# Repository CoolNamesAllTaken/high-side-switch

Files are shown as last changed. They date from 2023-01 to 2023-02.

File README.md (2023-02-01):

# high-side-switch
High side load switch for automotive and aerospace applications.

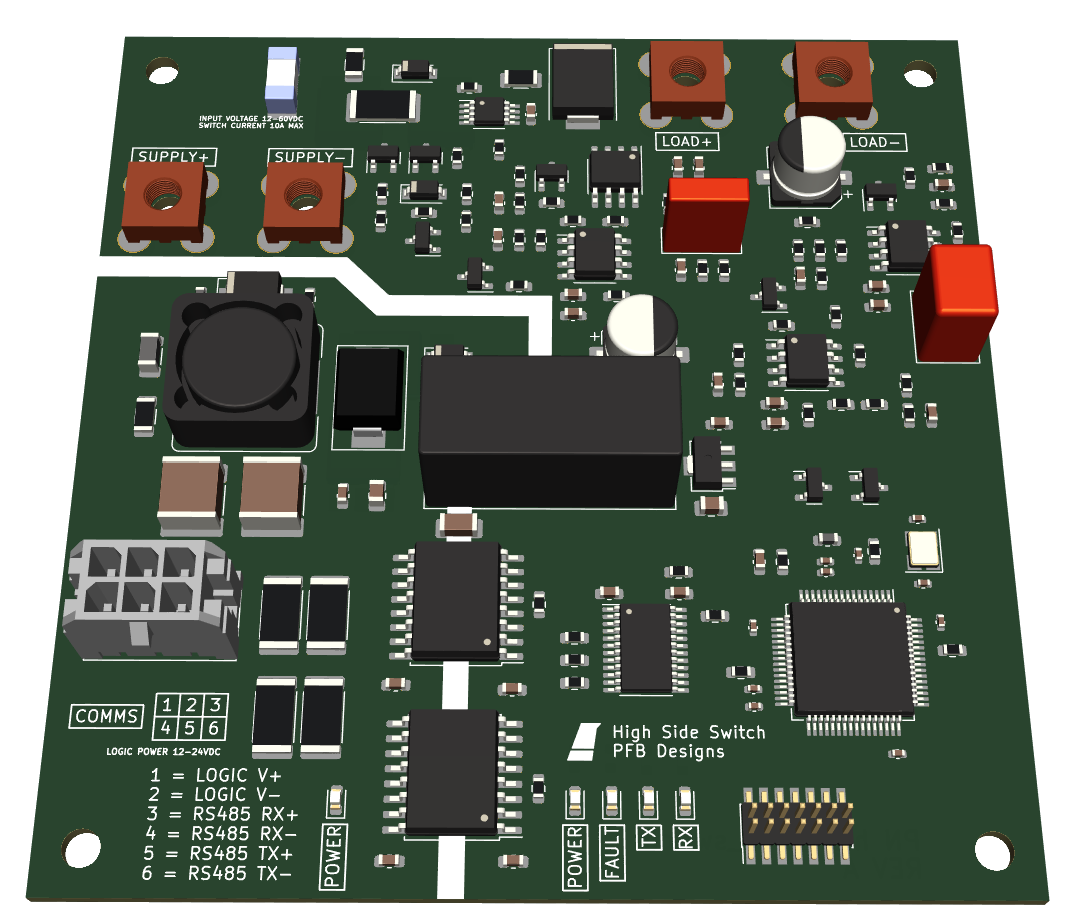
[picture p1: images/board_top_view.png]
Board top view.

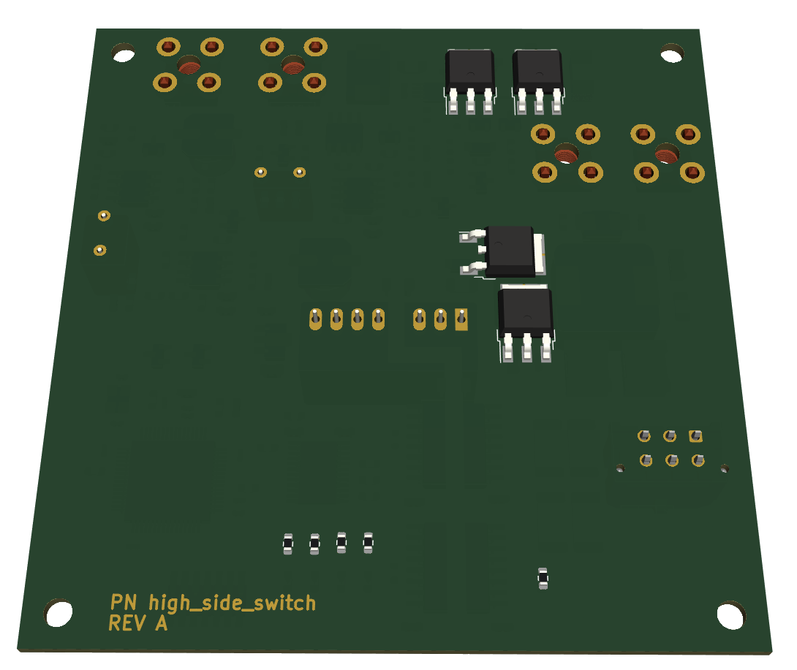
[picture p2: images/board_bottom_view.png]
Board bottom view.

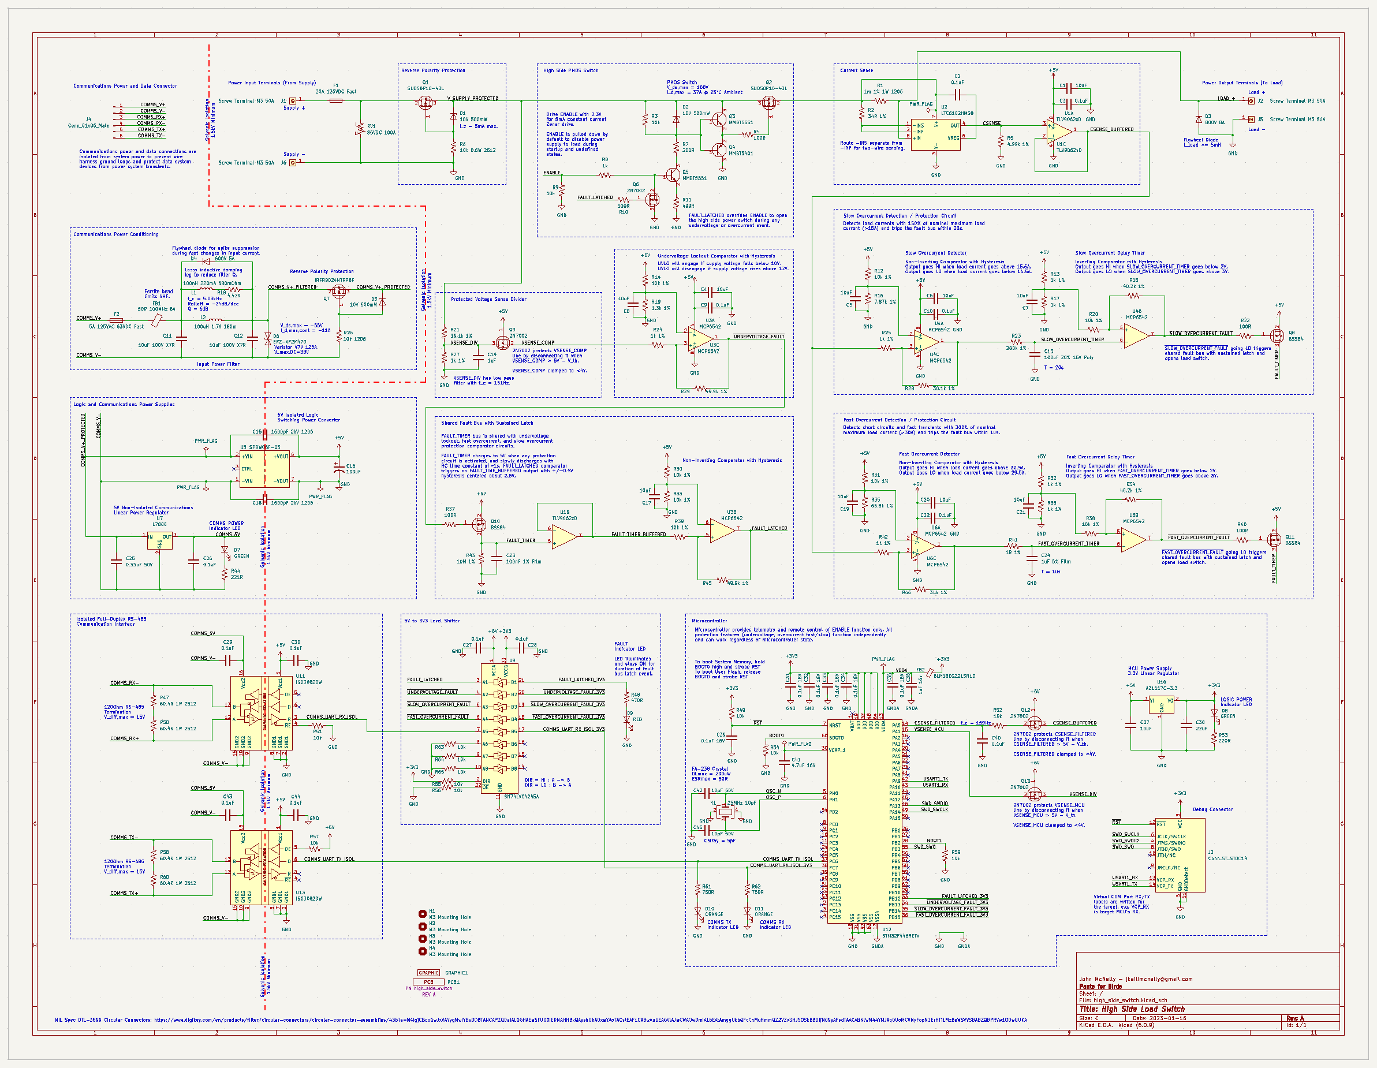
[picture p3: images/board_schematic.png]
Board schematic.


[Design Notes](word/design_notes_high_side_switch.pdf)

[Design Presentation](affinity/Onsite_Presentation_Reliable_Robotics.pdf)

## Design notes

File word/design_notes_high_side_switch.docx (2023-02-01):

# Remote Load Switch

Design Notes

John McNelly

jkailimcnelly@gmail.com

# Design Requirements

This design is required to switch 12-60VDC power into a resistive and inductive load ( L_(load) ≤5mH ). Control signals must be received from, and load measurements with a resolution of 10mA must be reported to, a remote control computer up to 100ft away. The switch must be capable of operating continuously and may be cycled on and off at a frequency lower than 1Hz. The overall design should be tolerant of temperatures between -40°C to +70°C, standard atmospheric pressure, some conducted and radiated EMI, and moderate mechanical shock and vibration.

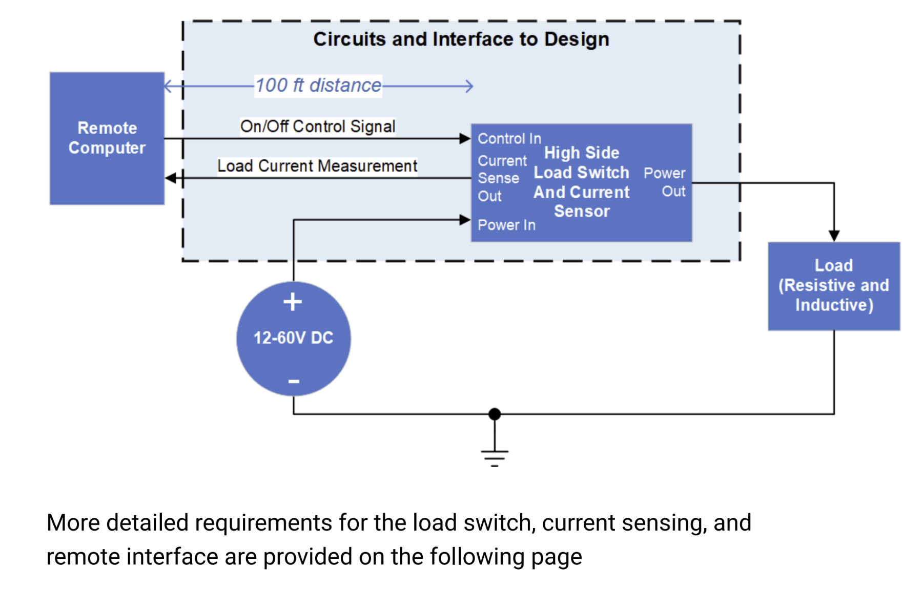
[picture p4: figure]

# Design Approach

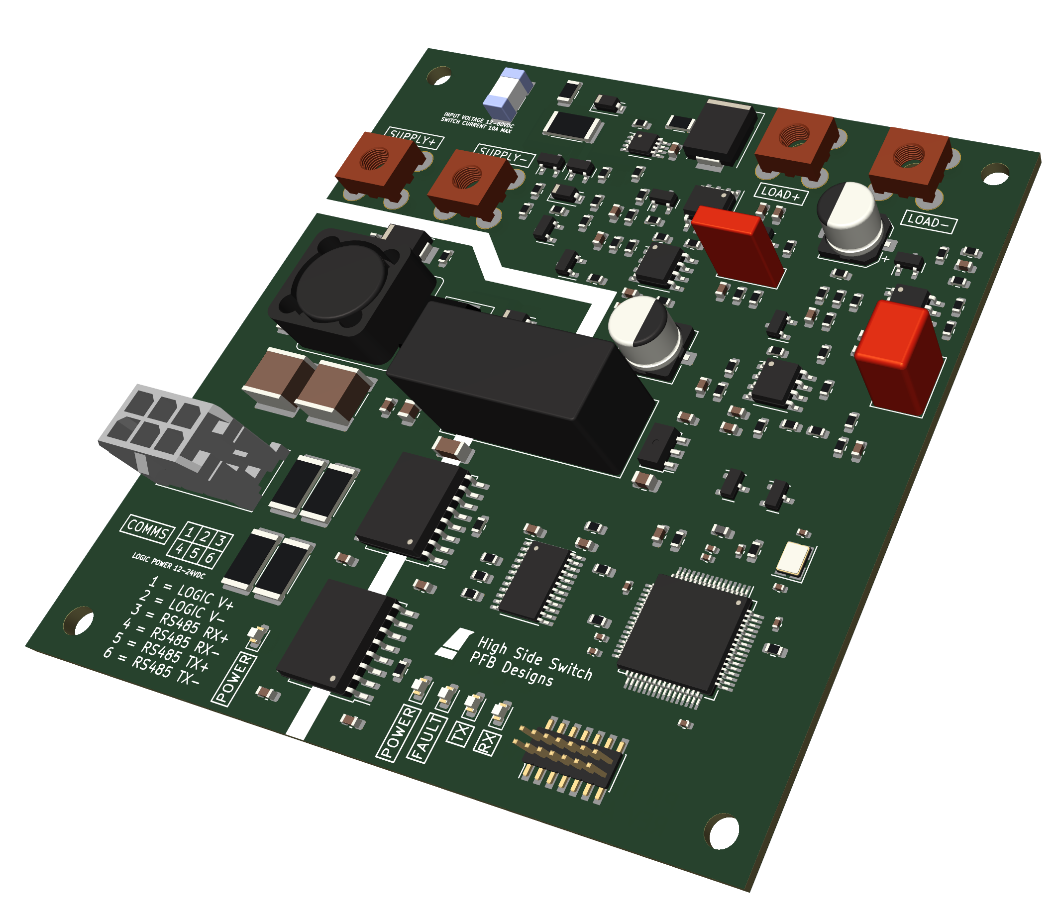
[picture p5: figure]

The High Side Switch device was designed to meet the performance criteria with simplicity and reliability in mind. Critical components such as switching transistors and power dissipating elements are oversized for the nominal use case and adequately derated for their operating environment. A number of operating scenarios that could result in potentially severe electrical failure modes were anticipated during the design process, and mitigated through the addition of circuitry that protects the device from undervoltage of the load power supply and two distinct load overcurrent scenarios (fast / slow overcurrent protection). In scenarios where protection of the device from damage was not possible within the design constraints, such as severe overvoltage (>100V), failure modes were deliberately engineered to encourage the device to fail into a “safe” state (i.e. load disconnected from the power supply).

The High Side Switch’s protection and sensing circuitry relies entirely on analog circuits in order to trigger device protections and filter measured values. This results in a simple, fast-acting, continuously-monitoring system that performs internal protection functions regardless of the state of the onboard microcontroller. This also means that the required firmware for this device is simple and has very low performance requirements, as it only needs to handle device communication and monitor a latching fault bus a few times per second.

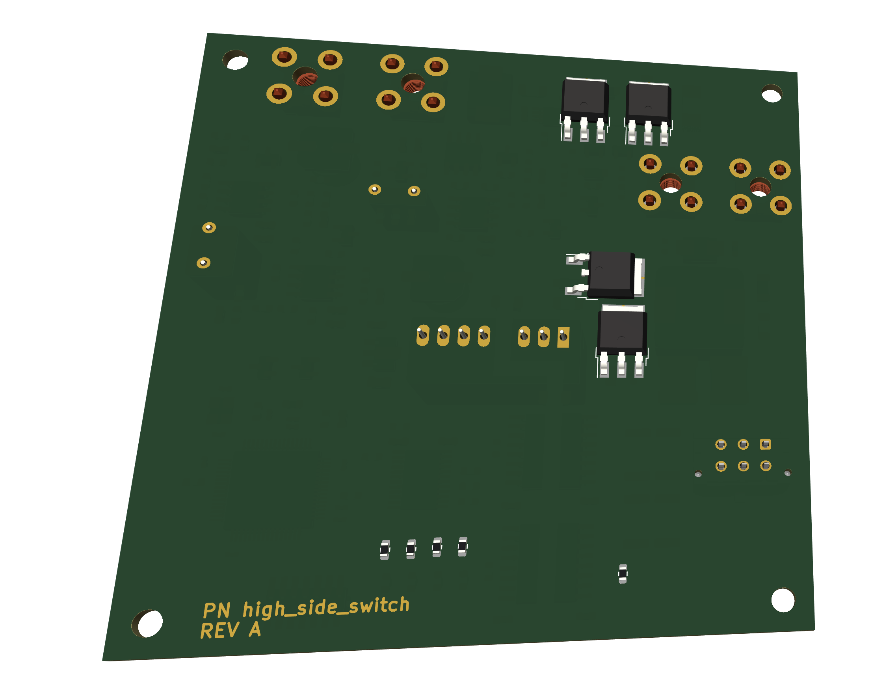
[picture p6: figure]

The High Side Switch is intended to be mounted into a metal enclosure for environmental protection. Heat-dissipating components are installed on the bottom of the board in order to allow easy cooling to an enclosure chassis with thermal pads or similar materials. Data connections are made with automotive-grade wire to board connections (intended for connection to a panel-mounted aerospace-grade enclosure connector). Power connection points are designed with high current board-mounted screw terminals in order to provide direct connections to ring terminals and associated enclosure-mounted aerospace-grade connectors.

System-level protection and ease of use were also considered during design of the High Side Switch. By isolating communications power and data from the load power supply, the High Side Switch can be utilized in systems where the load and the remote control computer have different common mode voltage potentials. Additionally, galvanic isolation between these nets ensures that the High Side switch will not serve as a common ground point between the two systems, thereby removing the potential for ground loops. Operation of the High Side Switch with a shared power supply is also possible, with no extra steps required for installation or use.

The High Side Switch utilizes an isolated UART over RS-485 interface for communication, in order to simplify requirements for the remote control computer to a single interface that is used for switch control, current measurements, and error monitoring. The High Side Switch is intended to be used in a single-master RS-485 connection, with a point to point connection between the High Side Switch and the remote computer, and no other devices on the bus (remote computer is the master).

The High Side Switch favors discrete design with readily substitutable general-purpose components in order to manage costs and provide a robust supply chain for long-term producibility.

# Design Explanation

## System Power Input

### Schematic

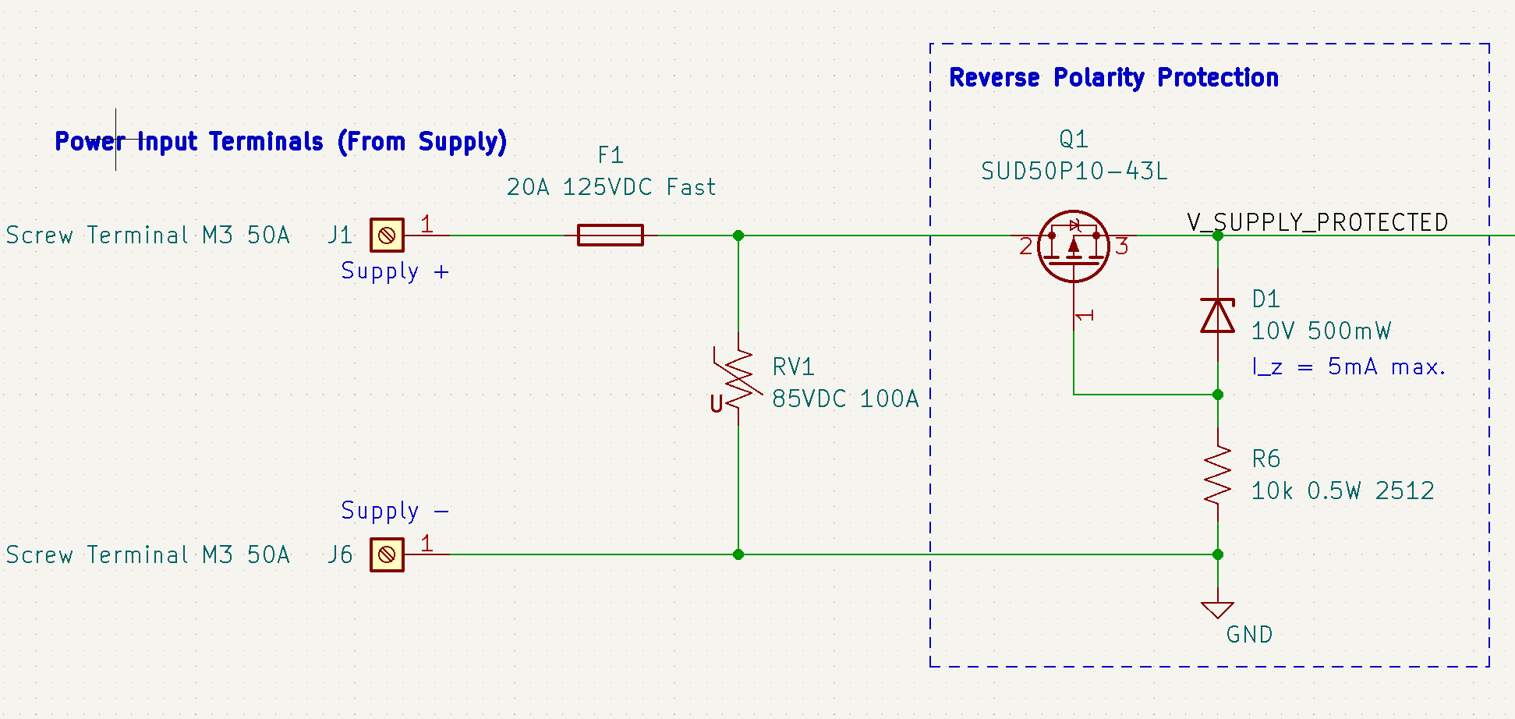
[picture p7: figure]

System power is protected against reverse polarity using a PMOS transistor connected drain-first. In the nominal polarity configuration, current flows through the PMOS body diode and then through the Zener diode (D1) and current limiting resistor (R6), generating a -10V gate-source voltage on the PMOS transistor that turns on the MOSFET. In the reverse polarity configuration, current flows up through the current limiting resistor and the diode, generating a +Vf gate-source voltage on the PMOS transistor that turns it off, where Vf is the forward voltage of the Zener diode (D1).

Auxiliary protection against overvoltage and overcurrent is provided with a 20A fuse (F1) and a metal oxide varistor (RV1). The varistor is designed to crowbar the supply rails and blow the fuse during an overvoltage event, thereby disabling the circuit’s power input and reducing the likelihood that an overvoltage event causes the primary PMOS switch to fail closed. The fuse also provides protection in the case that downstream overcurrent protection circuitry fails to open the main PMOS transistor during an overcurrent event. The fuse current rating and trip curve is selected such that it takes significantly longer to trip than the overcurrent protection circuitry during a large current spike, thereby reducing the chance of false positive fuse blown events.

### Calculations

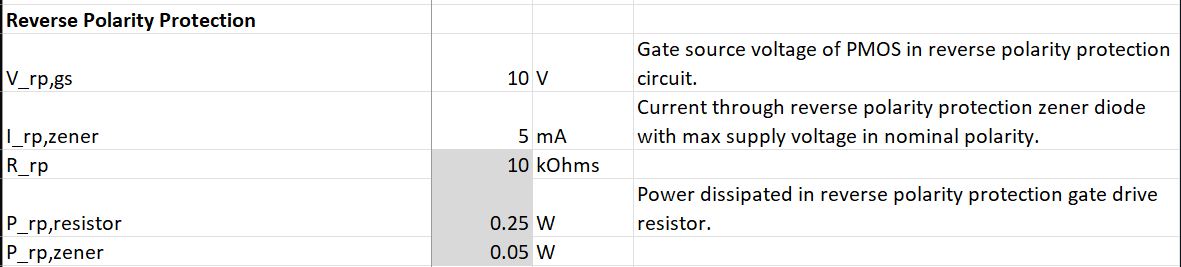
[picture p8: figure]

### PCB Layout

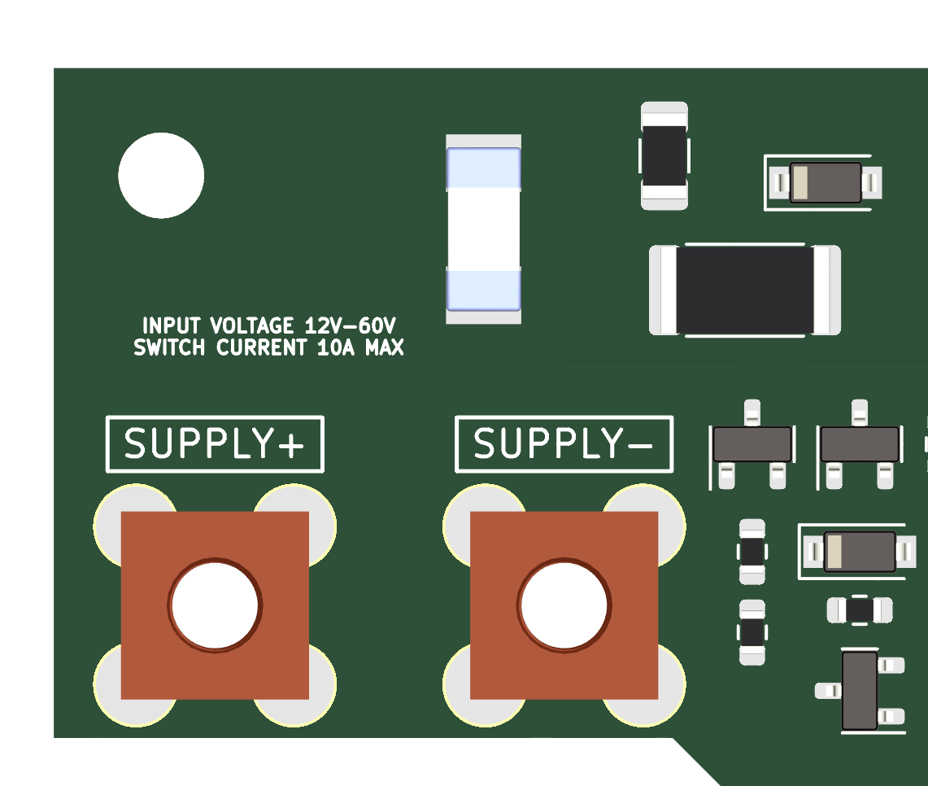
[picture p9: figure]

System power (i.e. the power connected to the load) is fed into the remote load switch via high-current M3 screw terminals bonded directly to the PCB.

## Load Switch

### Schematic

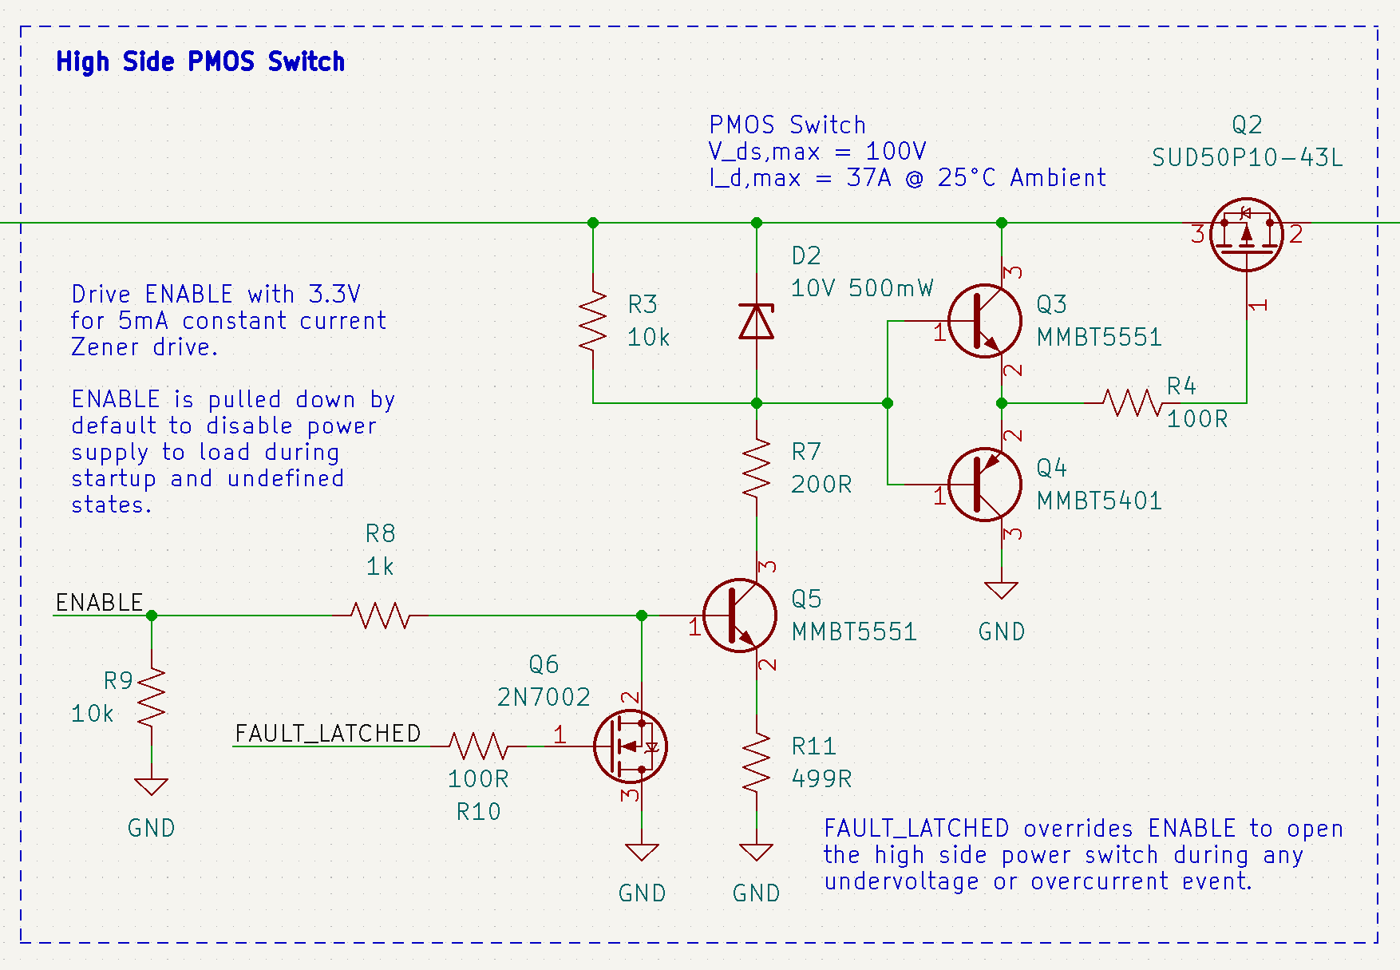
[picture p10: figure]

The load switch uses a PMOS transistor to control the current flowing to the load through the positive supply rail. Gate drive of the PMOS transistor is achieved with a Zener diode (D2) and pullup resistor (R3) which synthesize a -10V gate voltage and a totem pole BJT pair (Q3 and Q4) used for fast gate drive. A gate resistor (R4) can be used to adjust gate resistance to limit EMI and damp oscillations in the PMOS transistor.

Normally, the Zener diode (D2) in this circuit would be pulled to ground through a single current limiting resistor, but the wide power supply voltage range would result in widely variable Zener currents (and hence, variable power dissipation in the current limiting resistor). This would make turn-on time and gate voltage dependent on supply voltage, and would make the power dissipated in the current limiting resistor proportional to the square of the supply voltage ( P=V^2 /R ). A BJT current source (Q5) is used in conjunction with a constant base drive voltage (3.3V) to hold the Zener current steady while supply voltage varies. This makes the power dissipated in the current limiting resistor and the BJT dependent on supply voltage, but only linearly as current remains constant ( P=IV ). Care is taken to select a Zener drive current such that the Zener turns on quickly and is fully saturated, while not exceeding power dissipation requirements in Q5 during high voltage supply scenarios. The simulation plot below shows current through the Zener diode (plotted in red) holding steady while supply voltage varies (plotted in green).

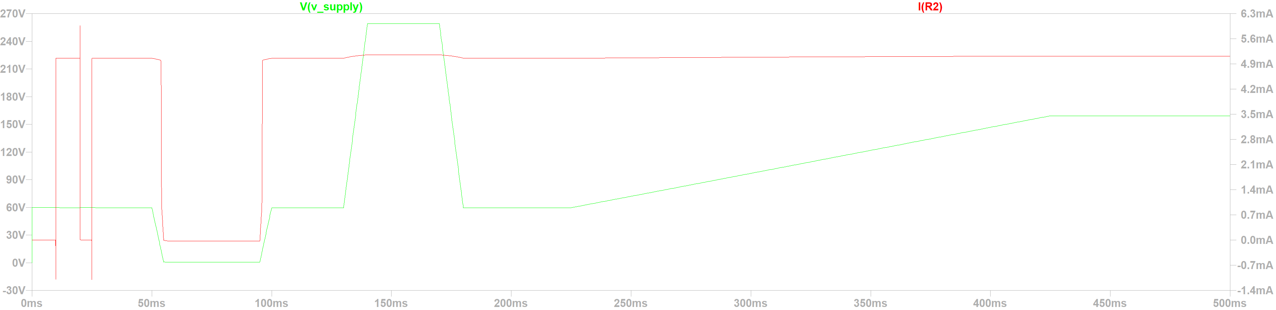
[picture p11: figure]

The PMOS transistor is turned on and off by toggling the ENABLE line connected to the base of Q6. ENABLE has a base resistor to limit current into Q6, as well as a pulldown resistor to make sure the PMOS transistor is OFF during startup and undefined states.

System faults can override the PMOS transistor with a fail-open behavior by pulling ENABLE to ground via Q6 whenever the FAULT_LATCHED line is HI.

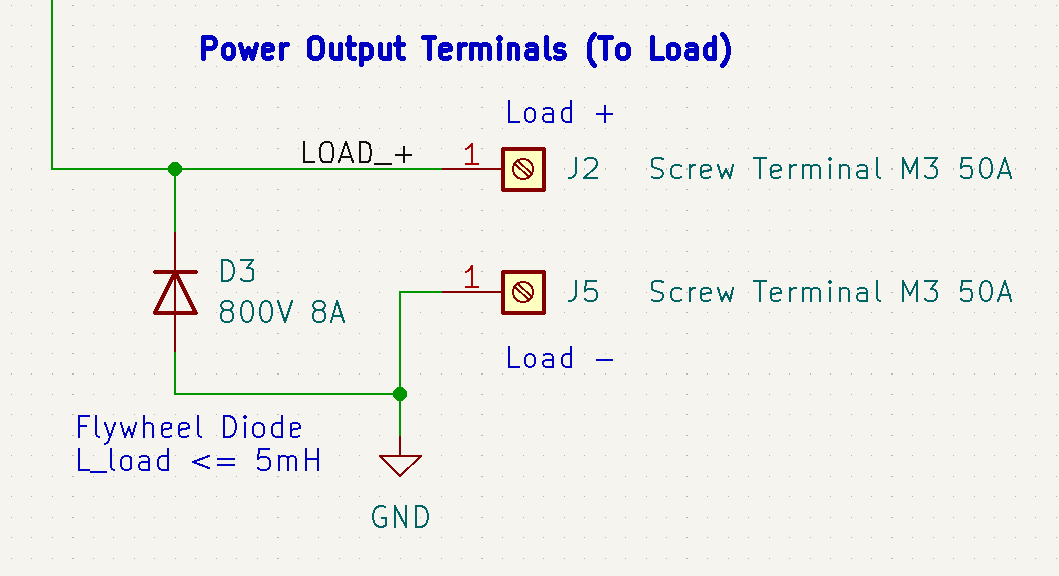
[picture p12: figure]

A flywheel diode is included across the power output terminals in order to protect the PMOS switch and other components from voltage spikes caused by switching an inductive load.

### Calculations

### PCB Layout

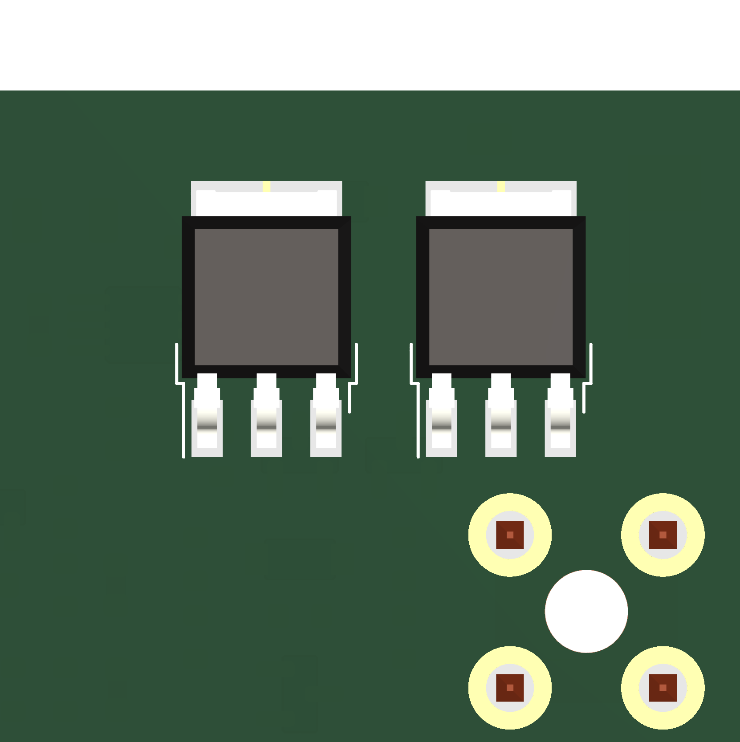
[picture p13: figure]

The load switch drive components are located on the top of the PCB adjacent to the system power supply input. Both the reverse polarity protection PMOS and the load switch PMOS are located on the bottom side of the board to allow heatsinking to a metal enclosure.

## Current Sense

### Schematic

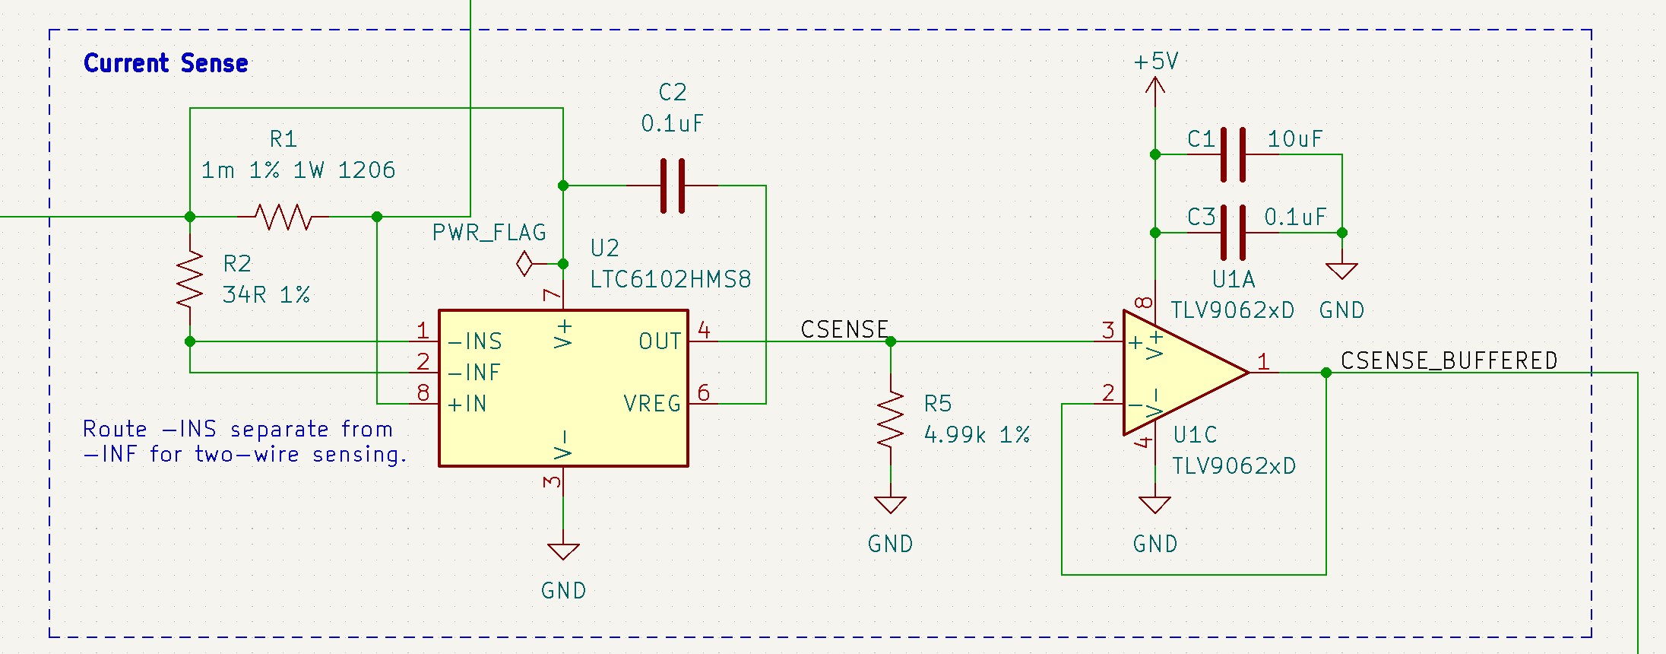
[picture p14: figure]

Current sensing is achieved with an LTC6102 high-side zero-drive precision current sense amplifier. This IC has an internal op-amp control circuit that matches the voltage drop across the sense resistor (R1) with the voltage drop across and input resistor (R2). The current flowing through the input resistor is then fed into an output resistor (R5) which creates a GND-referenced analog voltage that is proportional to the current flowing through the sense resistor.

The current sense voltage CSENSE is buffered by a TLV9062 rail-to-rail op amp to prepare it for further distribution and filtering elsewhere in the circuit.

### Calculations

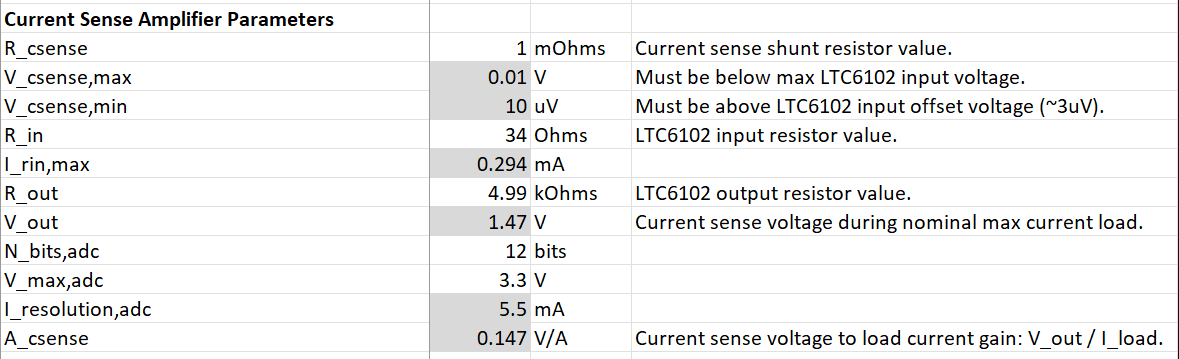
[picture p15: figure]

Note that in the maximum load current scenario, the output of the current sense amplifier is only 1.47V, since additional headroom is needed in order to measure current for triggering overcurrent protection at 150% and 300% nominal load current thresholds. Even with this reduced output voltage range, a 12-bit ADC can theoretically get 5.5mA resolution (but it probably won’t be pretty). If high resolution current sense is a strong driving requirement, additional amplification (with a 3.3V rail) could be added with another op-amp stage before the microcontroller ADC input.

## Overcurrent Detection

### Schematic

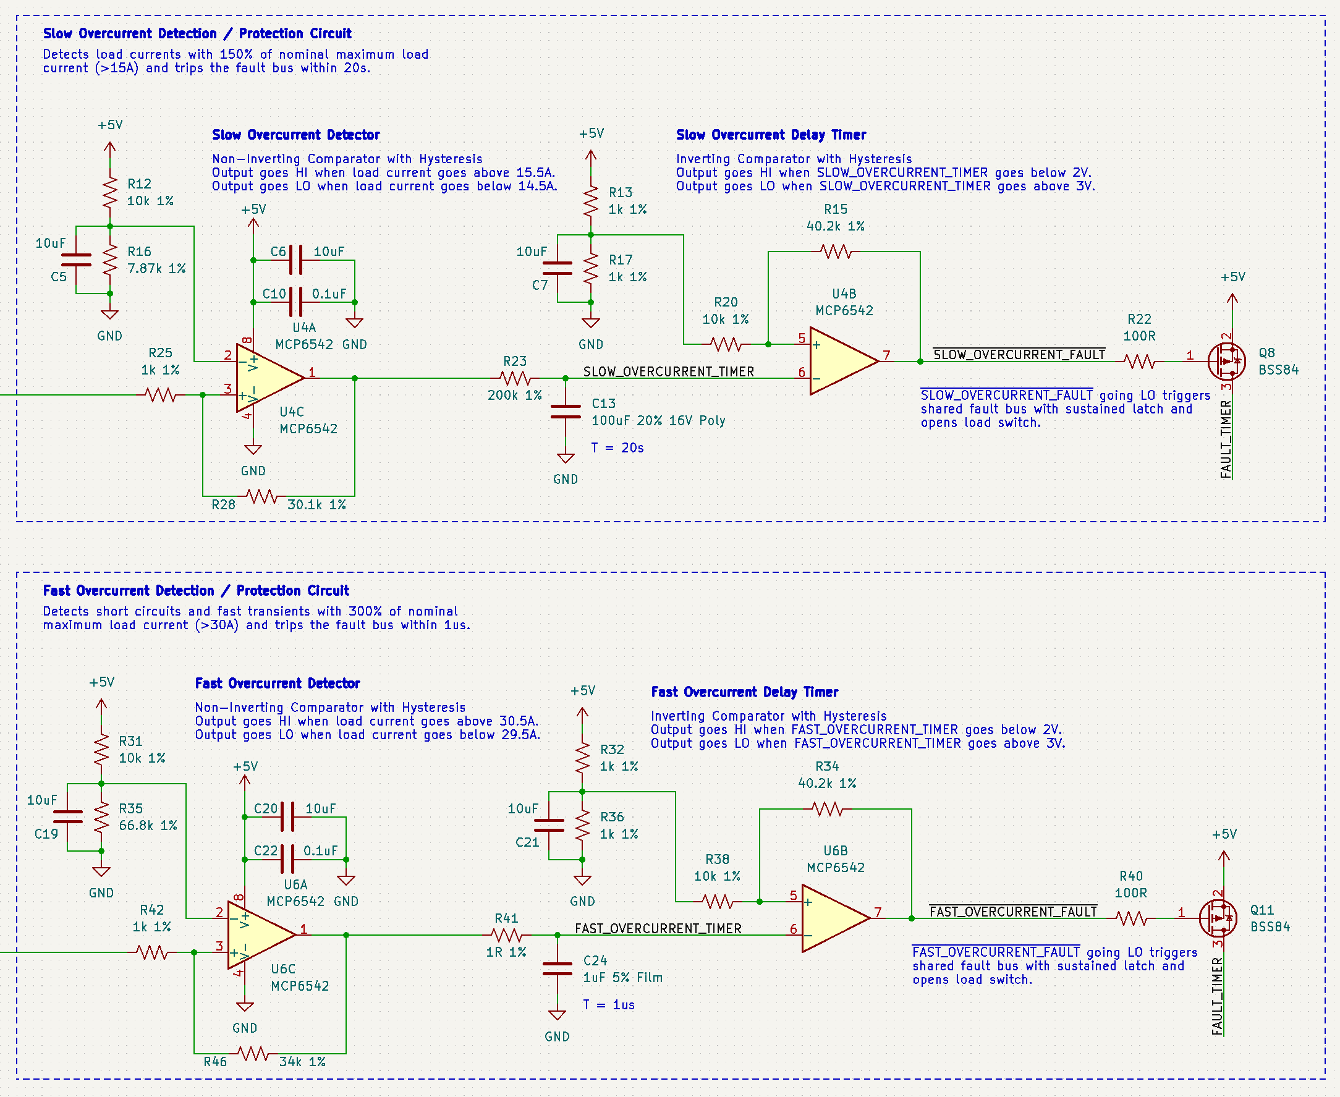
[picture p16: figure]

Overcurrent protection is provided with two separate thresholds and trip times, a 300% (30A) for 1us trip threshold (fast overcurrent protection), and a 150% (15A) for 20s trip threshold (slow overcurrent protection). This approximately mimics the trip curve of a B-curve circuit breaker, and allows for protection of the PMOS switch wiring harnesses running to the supply or load, and downstream / upstream devices. Fast overcurrent protection is intended to guard against short circuits (fast time constant) while keeping the trip current high enough that it does not get tripped by the inrush current of typical capacitive loads (similar function to the coil of a circuit breaker). Slow overcurrent protection is intended to guard against continuous overcurrent that could result in thermal damage (slow time constant, low trip current threshold, similar to the thermal trip mechanism inside a circuit breaker).

The slow overcurrent protection circuit first feeds the current sense signal into a current comparator (U4A), which determines whether the slow overcurrent threshold is currently being exceeded. If it is, the current comparator charges an RC timing circuit with a specifically designed rise time. Once this timing circuit charges to a voltage that exceeds the trip threshold of the connected timer comparator (U4B), a slow overcurrent fault is asserted on the SLOW_OVERCURRENT_FAULT bus, which turns on a PMOS signal MOSFET to charge up the shared FAULT_TIMER bus. This FAULT_TIMER bus results in the fault being latched for a set period of time, which reports the issue to the microcontroller, illuminates a FAULT indicator LED, and disables the load PMOS switch.

The fast overcurrent protection circuit works identically to the slow overcurrent protection circuit, except that the timing circuit has different values (for a faster time constant), and the trip threshold on the current comparator is higher (300% overload current, instead of 150%).

All comparators used in these circuits (and the rest of the design) include hysteresis in order to avoid oscillation when crossing a trip threshold. Comparator reference voltages are synthesized with a resistive divider and a filter cap to reduce fluctuations due to noise. Dual comparators are used in order to reduce layout space claim and improve PCB routing.

### Calculations

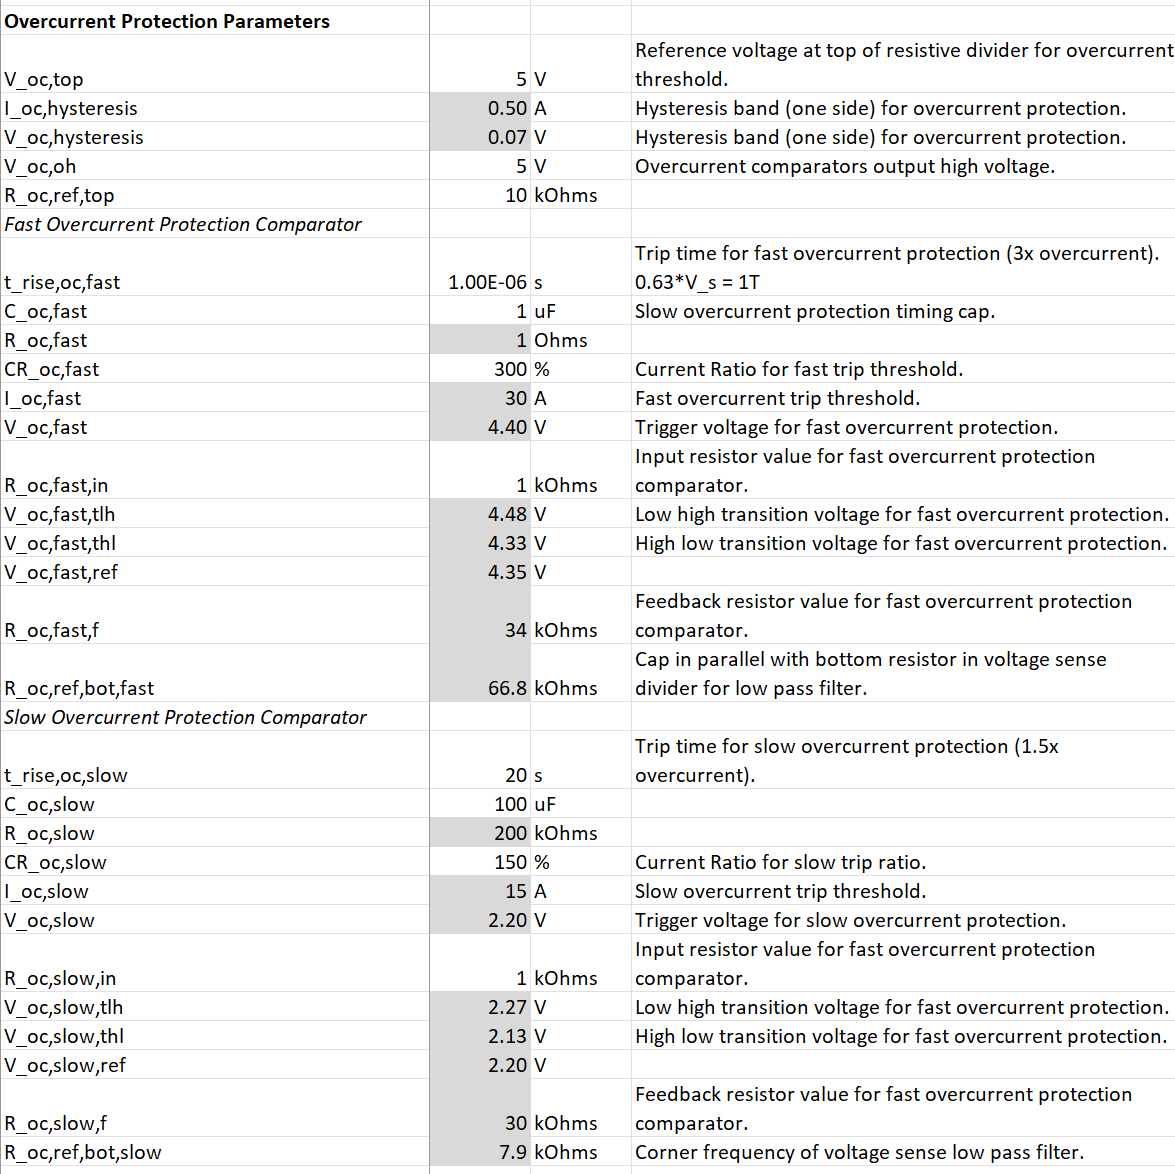
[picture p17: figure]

### PCB Layout

Nothing that special. Timing caps are Mylar for better accuracy / no voltage dependent weirdness. Large 100uF timing cap is polymer, since a Mylar cap of that size would be very expensive and a looser timing spec for slow overcurrent protection seemed acceptable. Could up the resistor value and go with a smaller Mylar cap if necessary.

## Voltage Sensing and Undervoltage Detection

### Schematic

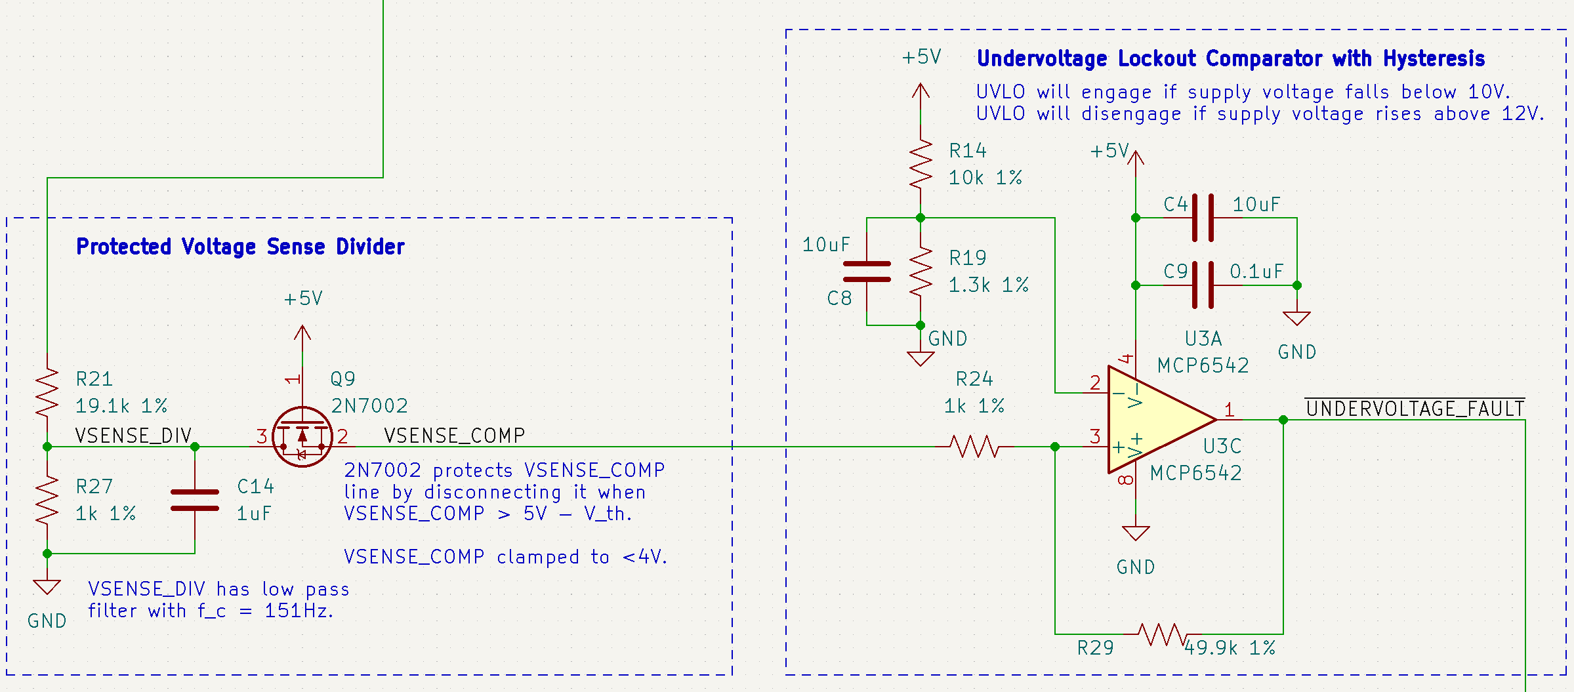
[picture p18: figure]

Voltage detection is accomplished with a simple voltage divider that includes a filter capacitor. Protection from overvoltage events is provided with a 2N7002 signal NMOS transistor (Q9) that is connected drain-first. If the divided voltage goes above 5V-Vth (where Vth is the threshold voltage of the MOSFET), the NMOS transistor turns off and isolates any downstream devices from the divided voltage signal.

Undervoltage protection is provided with a comparator that triggers an undervoltage fault on the shared FAULT_TIMER bus whenever the voltage drops below the level where the primary load PMOS switch can be fully turned on (around 10V). Hysteresis is provided to avoid undervoltage lockout oscillation while the supply voltage increases above the lockout threshold.

### Calculations

### PCB Layout

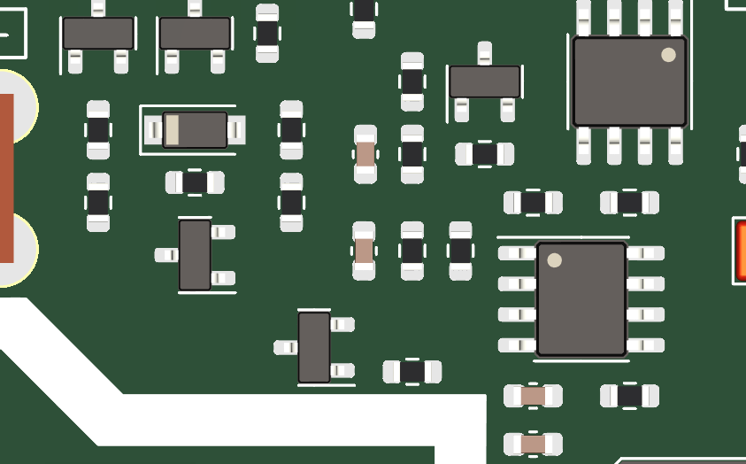
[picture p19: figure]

## Shared Fault Bus with Sustained Latch

### Schematic

Undercurrent and overcurrent fault events can be too brief for a microcontroller to read without using interrupts, and if an undervoltage or overcurrent fault occurs but is immediately cleared, the load can enter a cycle of continuous faulting where the load is disabled, the fault is cleared, the load is re-enabled, and the fault occurs again. This can result in an unwanted PWM-like behavior where the load current or voltage is regulated to a level near the trip threshold, possibly resulting in damage to components or wiring and suppressing reporting of the system fault. The solution to this problem is to latch any fault that occurs for a minimum amount of time, such that the microcontroller can easily report it, and the automatic “retry” time where the load switch is re-enabled after the fault is cleared is long enough that intermittent repeating faults do not result in any long term damage.

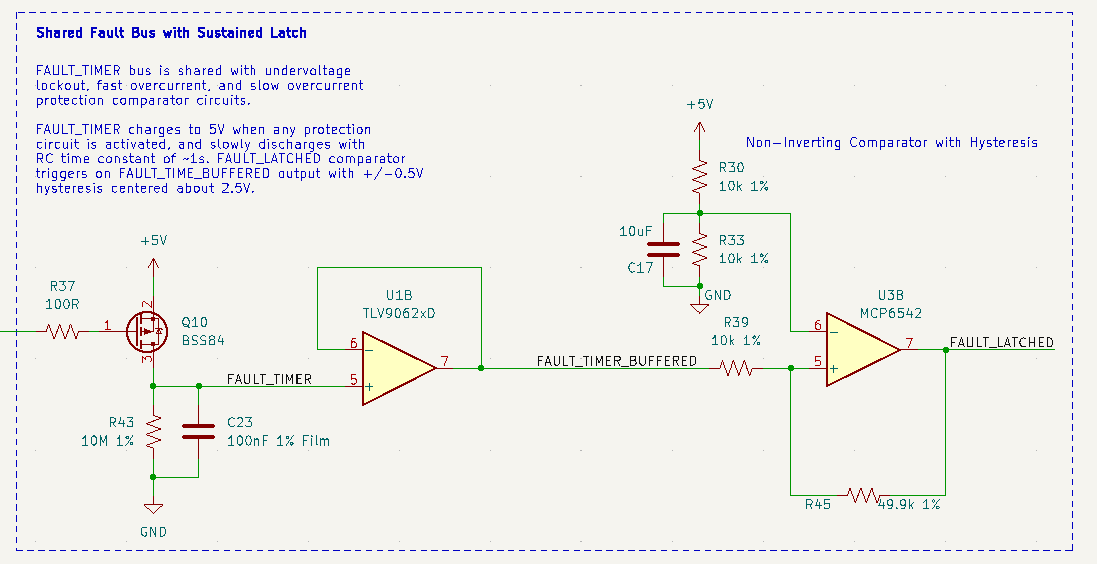
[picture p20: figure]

The various fault lines (SLOW_OVERCURRENT_FAULT, FAST_OVERCURRENT_FAULT, and UNDERVOLTAGE_FAULT) are each connected to a PMOS signal MOSFET that charges an RC timing circuit when any fault is tripped. The image above shows the fault MOSFET for the undervoltage protection circuit (Q10). The attached FAULT_TIMER RC timing circuit (R43 and C23) is charged up to +5V whenever any fault is tripped, and the timing capacitor (C23) slowly discharges through the parallel resistor (R43). The resulting RC time constant of around 1 second is used to keep the FAULT_LATCHED net HI until the FAULT_TIMER net has discharged below the threshold set by the fault timer comparator, which reads the FAULT_TIMER net through an op-amp buffer in order to not disturb its discharge time.

### Calculations

### PCB Layout

A Mylar timing cap is used for the FAULT_TIMER RC circuit due to its well-controlled capacitance.

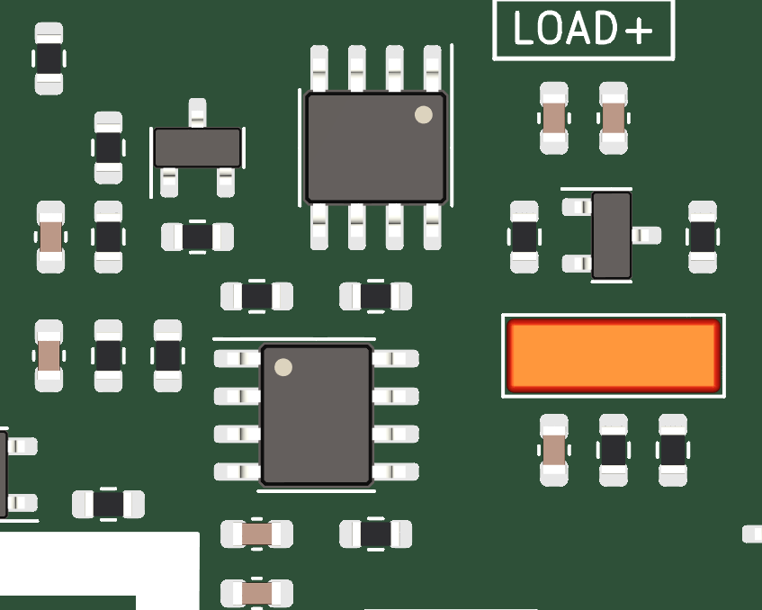
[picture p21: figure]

## Microcontroller

### Schematic

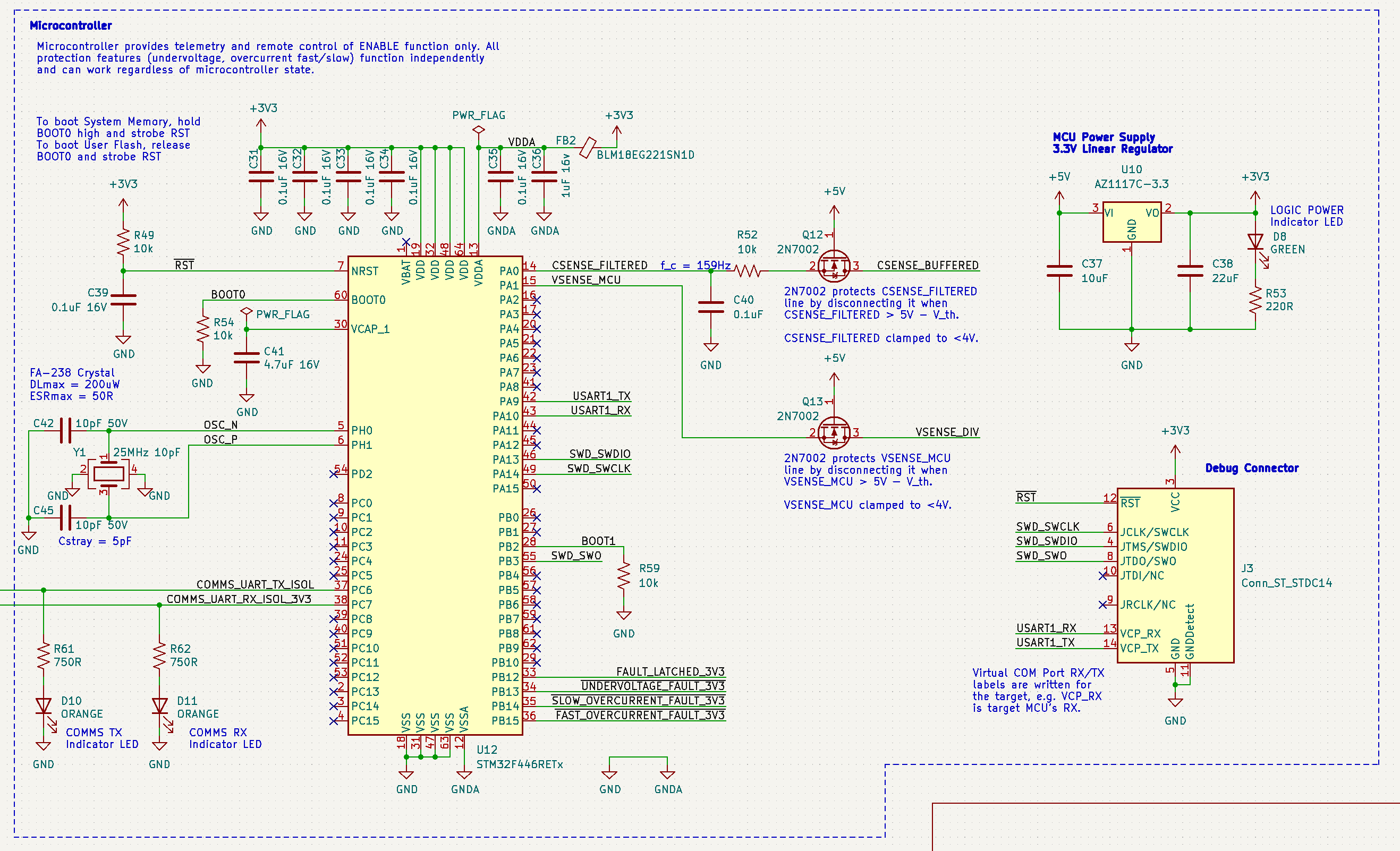
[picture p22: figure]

An STM32F446RET6 was selected as the microcontroller due to its ubiquitous interfaces, reasonable supply chain availability, well documented environmental ratings, and previous familiarity. The STM32’s internal 12-bit ADC is used for voltage and current sensing, while digital inputs are used to read bus fault signals. An external 25MHz crystal is provided in order to provide a more accurate clock frequency, which is helpful for UART at higher baud rates. USART peripherals are used in asynchronous mode as both a debug UART interface (USART1) and a primary device communication interface (USART6, on PC6 and PC7). Programming of the device is achieved over Serial Wire Debug (SWD) via a standard STDC14 debug connector.

The microcontroller is provided with a separate 5V to 3.3V linear regulator power supply, since it is the only device on the board that requires 3.3V for operation. Analog pins are provided with separate bypass capacitors, and the analog power supply is linked to the main 3.3V power supply with a ferrite bead for noise suppression. Additional protection and filtering is provided on the current and voltage sense lines in order to reduce noise and clamp voltages to a safe range for the microcontroller. An additional RC filter is not needed on the voltage sense line since the corner frequency is already in a desirable range due to the RC filter built into the primary voltage divider (not shown).

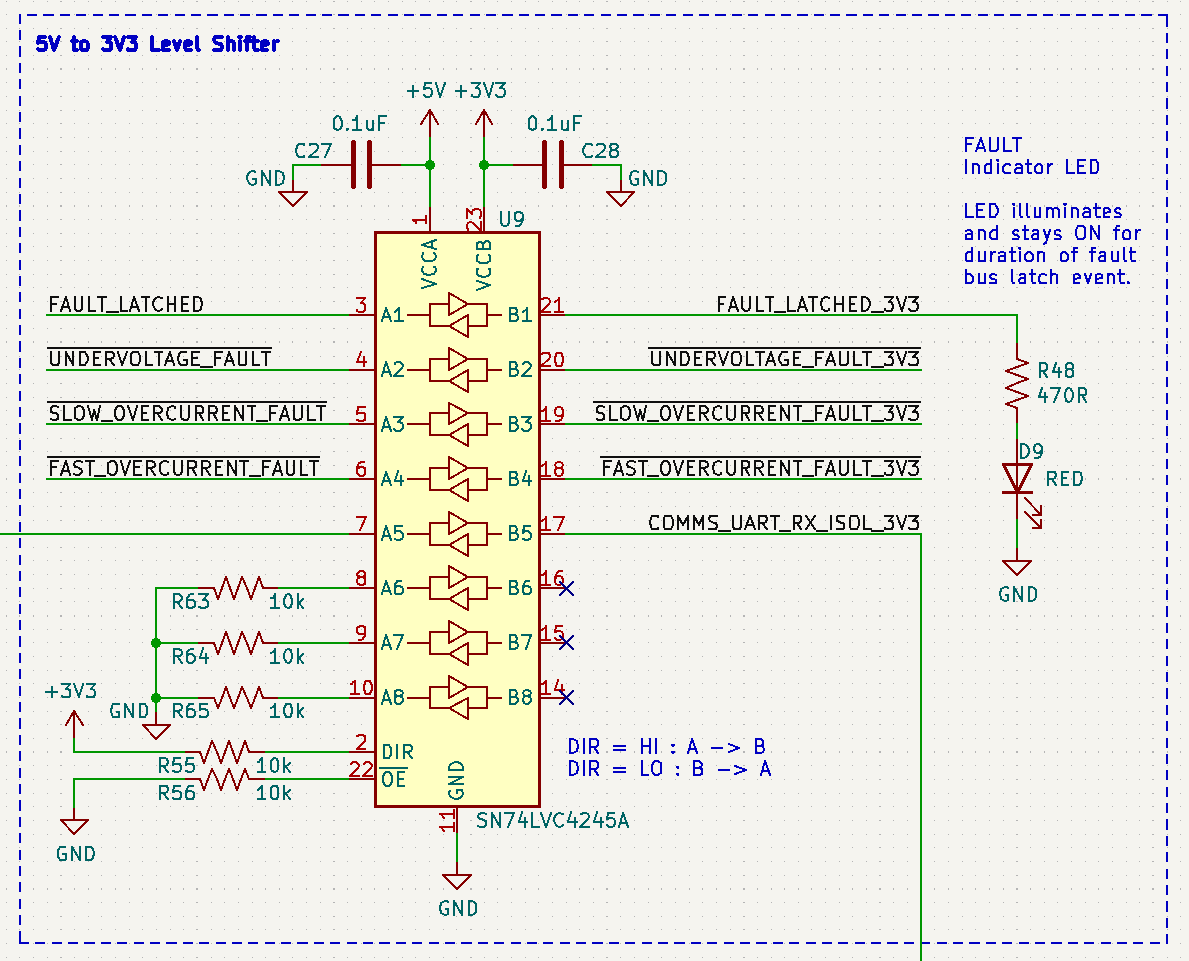
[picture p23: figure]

A level shifter is needed to convert many of the 5V signals from elsewhere on the board to 3.3V logic levels. Unused inputs are pulled to GND to avoid oscillations on the level shifter outputs that would occur if the inputs were left floating.

## PCB Layout

Indicator LEDs provide feedback to the user when the 3.3V power supply is on (green light), when a fault has been detected (red light), and when the primary device serial interface is transmitting or receiving (orange lights).

## Isolated Full-Duplex RS-485 Communication Interface

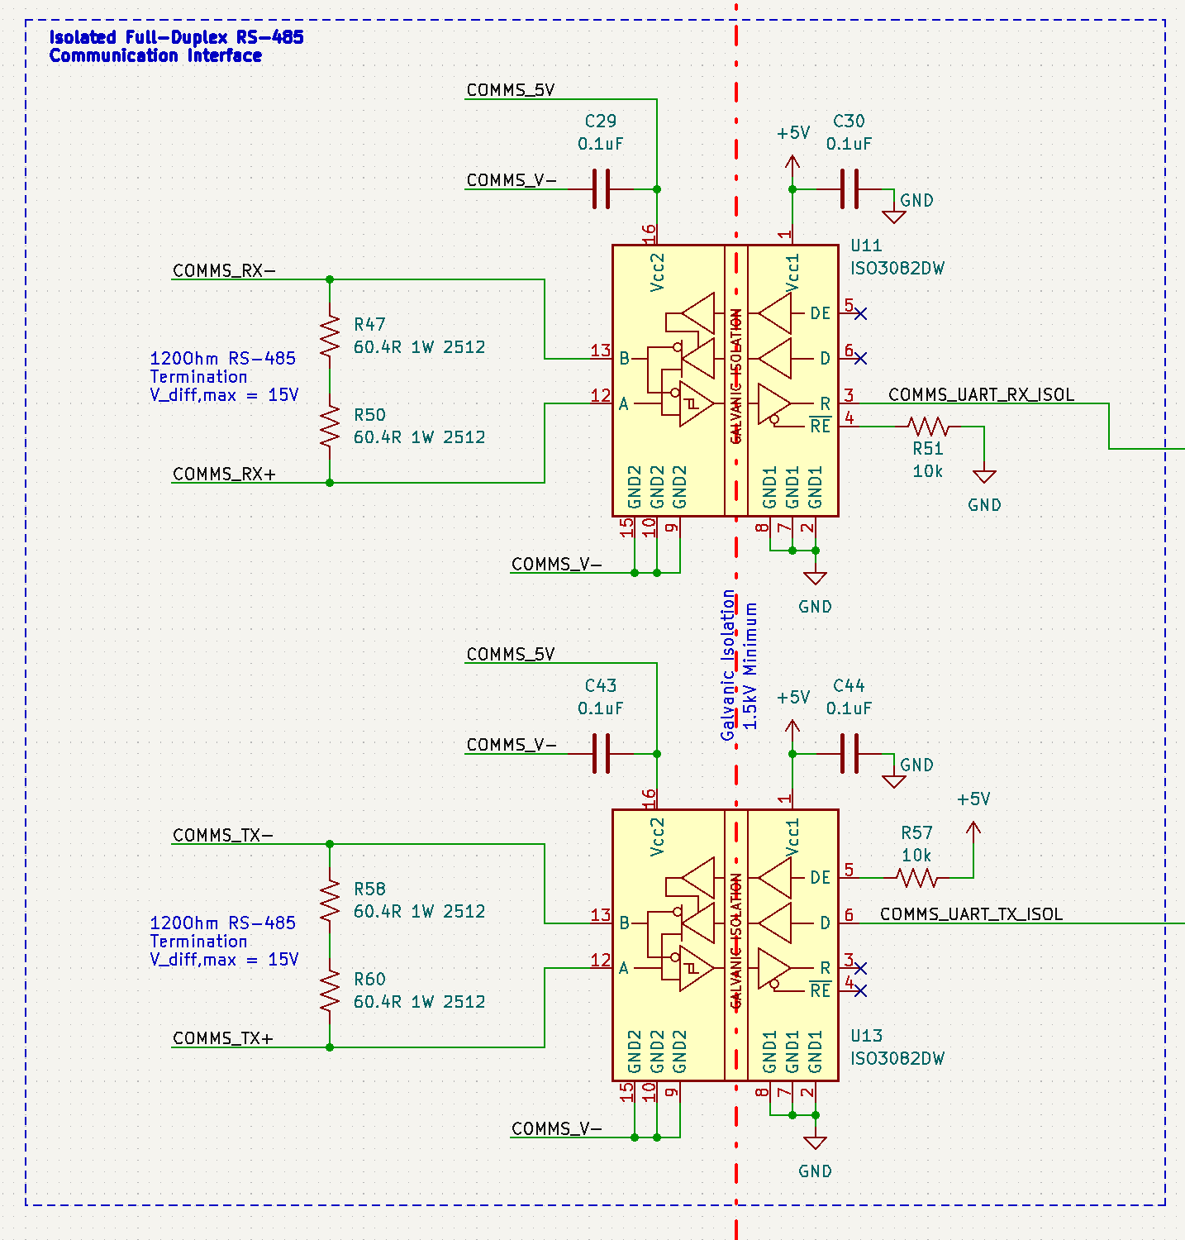
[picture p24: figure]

Device communication is conducted with UART over a galvanically isolated full-duplex RS-485 interface. Differentially-signaled RS-485 is immune to common mode interference and can run for thousands of feet under the right conditions, making it a good simple choice for long distance communication with the remote control computer. Since RS-485 is a fully digital interface, it can easily be isolated as shown in order to break any ground loops that might otherwise form in wiring harnesses, as well as provide protective separation between the communications bus and the primary DC power bus in the case of potentially hazardous voltage transients on one bus or the other.

Both TX and RX transceivers are terminated with a characteristic impedance of 120Ohms. The communication wiring harness should use a differential impedance of 120Ohms across the +/- signal wires for optimum performance. To reduce power dissipation, termination resistors (e.g. R58, R60) can be removed, in exchange for increased reflections and reduced performance. This tradeoff may be acceptable at low baud rates.

The isolated UART RX line is fed to the microcontroller’s UART port via a 5V to 3.3V level shifter. The isolated UART TX line is driven directly by the microcontroller, since its voltage levels are compatible with a 3.3V TTL logic input.

EACH RS-485 transceiver is galvanically isolated internally and provided with separate power supplies on either side of the isolation barrier.

### PCB Layout

1.5kV Isolation barrier is denoted in white. Conformal coating is required to satisfy electrical spacing at full isolation voltage.

## Logic and Communications Power Supplies

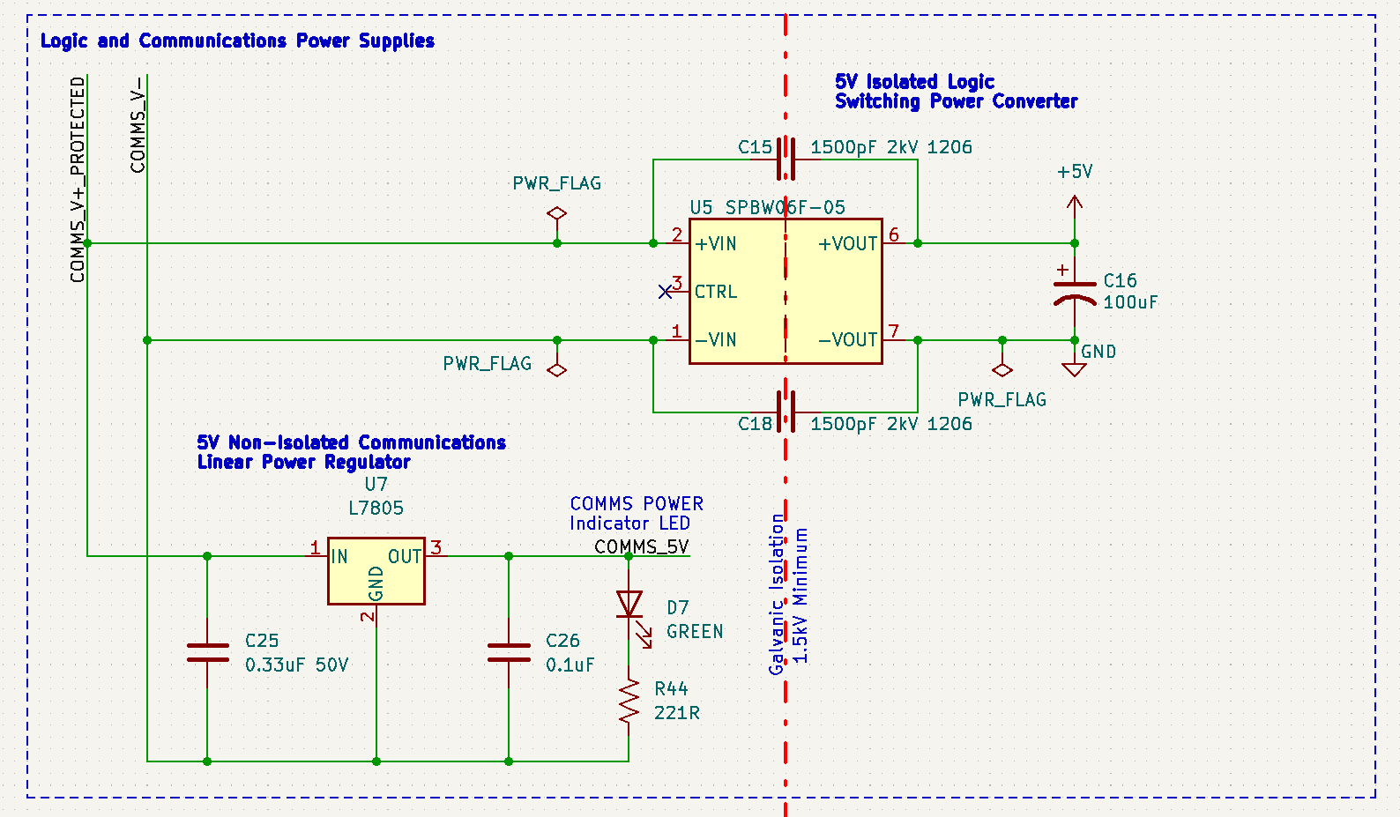
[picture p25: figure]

Power is supplied to the onboard communications and logic circuits via the COMMS connector. Non-isolated power is provided to the non-isolated side of the RS-485 transceivers via a linear regulator (U7), while isolated power is provided to the rest of the circuit through an isolated switching DC-DC converter (U5). The switching converter has an input voltage range of 9-36V while the linear regulator has an input range of up to 35V. The circuit is designed to accept a COMMS connector with 12-24VDC available across the LOGIC V+ and LOGIC V- pins.

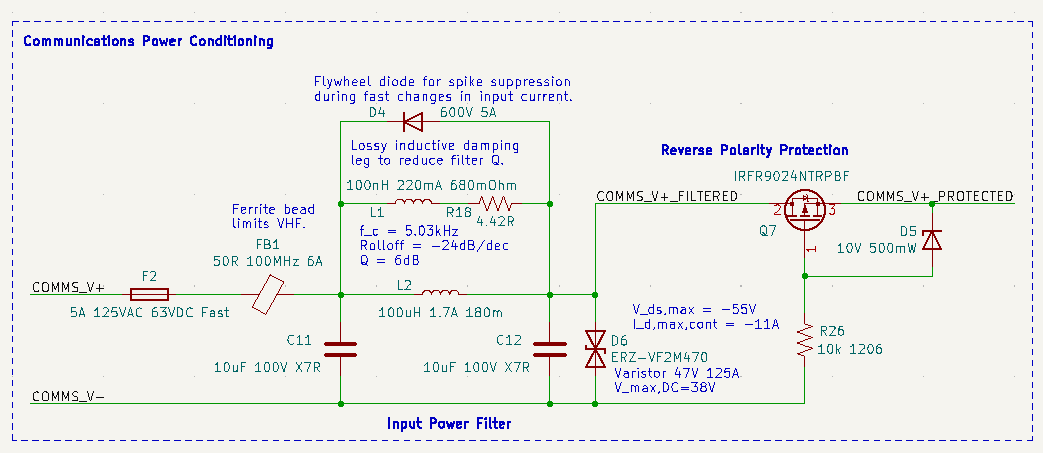
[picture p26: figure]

Protection is provided for the communications and logic circuit power supplies with a damped PI filter, input fuse, varistor, and reverse polarity protection circuit. The input PI filter and ferrite bead cut down on noise entering and leaving the device via the COMMS_V+ and COMMS_V- connections. Damping the inductor with a lossy parallel inductor allows significant reduction of device Q with small external components. A flywheel diode in parallel with the filter inductor suppresses voltage spikes resulting from sudden changes in input current. The reverse polarity protection circuit (Q7 and friends) is identical to the system power input reverse polarity protection circuit (Q1 and friends), but uses smaller components since it only needs to sustain load currents up to around 1A. The varistor (D6) provides an additional level of protection by absorbing overvoltage pulses that pass through the PI filter and blowing the input fuse if necessary to disable the device during a large overvoltage event.

### PCB Layout

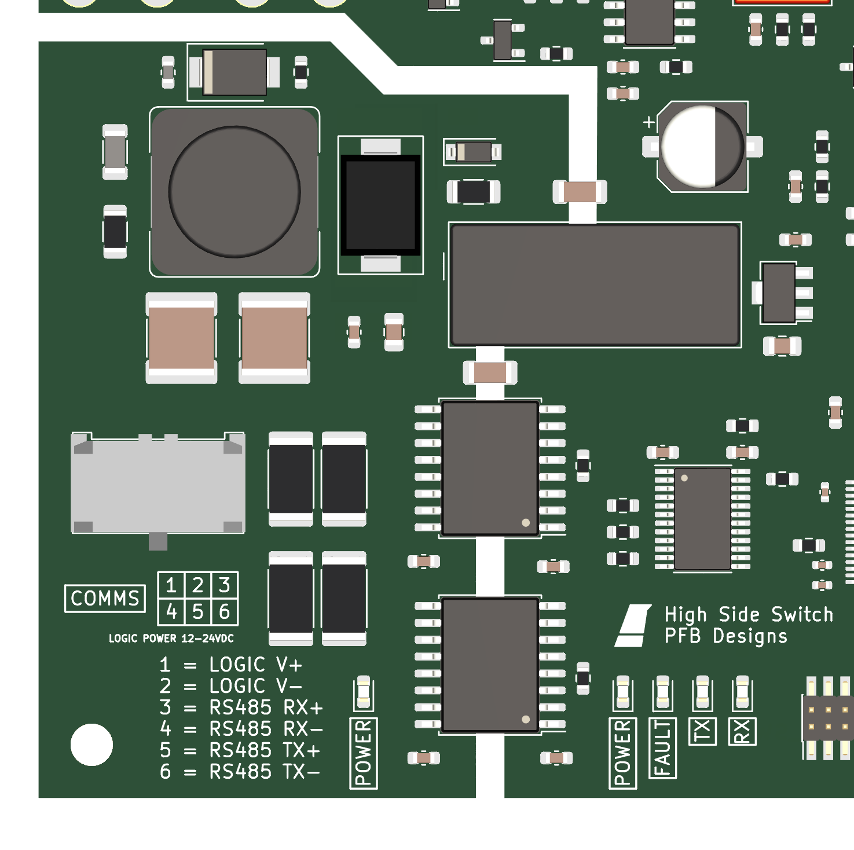
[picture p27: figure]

Revised 2022-01-29 High Side Switch Design Notes Page 2

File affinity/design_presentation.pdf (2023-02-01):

# Design Challenge: Remote Load Switch


# Power Requirements

Parameter | Value | Units | Note
Min | Typ | Max
Vsupply | 12 | | 60 | VDC | Voltage of supply to be switched.
I load | | | 10 | A | Current into load.
Lload | | | 5 | mH | Load inductance.
f switch | | | 1 | Hz | Continuous switching frequency.
- Probably want to switch high-side with a PMOS so load is at 0V when OFF.
- Inductive load needs flywheel diode for protection. No optimizations required for fast turn-off.
- Should oversize Vds and Ids of switching MOSFET to be safe.
- Gate drive requirements are pretty loose (not doing high frequency switching).

# Environmental Requirements

Parameter | Value | Units | Note
Min | Typ | Max
Tambient | -40 | | 70 | °C | Ambient temperature.
patm | 100 | | 10 | kPa | Atmospheric pressure.
EMI | | | Some | | Conducted / radiated EMI.
Shock / Vibe | | | Moderate | | Mechanical shock and vibration.
- Most industrial / commercial / automotive components meet the temperature spec.
- Don’t need to qualify for vacuum, but maybe add pressure relief to enclosures?
- Add filters to power supply for reduced EMI in and out.
- Use differential signals, galvanically isolate comms to reduce ground loops.
- Need to be careful with component mass and dimensions, may need potting or celastic on big / dangly stuff, lots of PCB mounting points. Test for vibe modes.

# Measurement and Communication Requirements

Parameter | Value | Units | Note
Min | Typ | Max
d comms | | | 100 | ft | Communication link distance.
ecurrent | -10 | | 10 | mA | Current measurement error.
f data | 100 | | | Hz | Data sample and reporting rate.
- Long data link distance, probably need differential signals with decent transceivers. Digitize analog signals for lower noise and simpler combined interface.
- Need pretty high resolution and accuracy for current measurement. Need to pay attention to component tolerances and ADC resolution. Dynamic range is ~1:1000 (12-bit ADC only has 4096 counts, and the last few bits aren’t usable).
- Data reporting rate is rather low, could probably get away with UART -> RS-485.

# Additional Thoughts

- Power switch needs to be fail-safe and difficult to damage.
- Reverse polarity protection, undervoltage protection, overcurrent protection.
- Need overcurrent protection to be fast-acting for short-circuits but compatible with capacitive loads.
- Unprotected failure modes should result in the switch failing open (load is OFF).
- Switch should self-recover from faults.
- Switch should be able to report fault conditions when / after they occur.
- Switch should be able to report bus voltage.

# Simplified Block Diagram


# Simplified Block Diagram: Power Input


# Power Input


# Simplified Block Diagram: Load Switch


# Load Switch


# Simplified Block Diagram: Current Sense


# Current Sense


# Simplified Block Diagram: Overcurrent Detection


# Overcurrent Detection


# Overcurrent Detection: PCB Layout


# Simplified Block Diagram: Voltage Sense / UVLO


# Voltage Sensing and Undervoltage Detection


# Simplified Block Diagram: Fault Bus


# Shared Fault Bus with Sustained Latch


# Simplified Block Diagram: Microcontroller


# Microcontroller


# Simplified Block Diagram: RS-485 Transciever


# Isolated RS-485 Comms Interface


# Simplified Block Diagram: Power Supplies


Not Shown!

# Power Supply Protection and Filtering


# Power Supplies


# PCB Layout



# Backup Slides

## Beep beep beep

# Project Links

## Project Github: https://github.com/CoolNamesAllTaken/high-side-switch

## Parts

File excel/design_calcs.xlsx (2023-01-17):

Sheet: Design Calculations
Symbol | Value | Units | Note
V_supply,min | 12 | V
V_supply,max | 60 | V
I_load,min | 0.01 | A | Minimum current sense resolution.
I_load,max | 10 | A
L_load,max | 5 | mH
Reverse Polarity Protection
V_rp,gs | 10 | V | Gate source voltage of PMOS in reverse polarity protection circuit.
I_rp,zener | 5 | mA | Current through reverse polarity protection zener diode with max supply voltage in nominal polarity.
R_rp | 10 | kOhms
P_rp,resistor | 0.25 | W | Power dissipated in reverse polarity protection gate drive resistor.
P_rp,zener | 0.05 | W
Current Sense Amplifier Parameters
R_csense | 1 | mOhms | Current sense shunt resistor value.
V_csense,max | 0.01 | V | Must be below max LTC6102 input voltage.
V_csense,min | 10 | uV | Must be above LTC6102 input offset voltage (~3uV).
R_in | 34 | Ohms | LTC6102 input resistor value.
I_rin,max | 0.294 | mA
R_out | 4.99 | kOhms | LTC6102 output resistor value.
V_out | 1.47 | V | Current sense voltage during nominal max current load.
N_bits,adc | 12 | bits
V_max,adc | 3.3 | V
I_resolution,adc | 5.5 | mA
A_csense | 0.147 | V/A | Current sense voltage to load current gain: V_out / I_load.
PMOS Switch Parameters
V_logic,high | 3.3 | V
P_switch,max | 5.8 | W | Max power dissipation allowed in PMOS switch at max rated temperature.
PMOS Gate Drive
V_drive,zener | 10
P_drive,zener | 0.05 | W | Power rating for gate drive zener.
I_drive,zener | 5 | mA
V_drive,be | 0.8 | V
R_drive,e | 500 | Ohms | Emitter resistor to set zener current for gate drive.
R_drive,c | 200 | Ohms | BJT collector resistor.
P_drive,c | 0.005 | W | Power absorbed by dissippation resistor on BJT collector.
V_drive,ce,max | 46.5 | V | Collector-emitter voltage across current source BJT.
P_drive,bjt | 0.2325 | W | Power dissipated in gate drive BJT while turned ON with max supply voltage.
V_drive,headroom,min | 4.3 | V | Minimum voltage used by drive circuitry (e.g. during low supply voltage operation). MOSFET gate drive voltage will be limited to V_supply,max - V_drive,headroom,min.
Low Supply Voltage Gate Drive Scenario
R_switch,ds,on,lv | 0.048 | Ohms | R_ds,on of PMOS switch in low supply voltage scenario. Gate drive zener is not fully saturated so this corresponds to the max R_ds,on of the PMOS switch.
P_switch,lv | 4.8 | W | Power dissipation in PMOS switch with max load current in low supply voltage scenario.
Overcurrent Protection Parameters
V_oc,top | 5 | V | Reference voltage at top of resistive divider for overcurrent threshold.
I_oc,hysteresis | 0.50 | A | Hysteresis band (one side) for overcurrent protection.
V_oc,hysteresis | 0.07 | V | Hysteresis band (one side) for overcurrent protection.
V_oc,oh | 5 | V | Overcurrent comparators output high voltage.
R_oc,ref,top | 10 | kOhms
Fast Overcurrent Protection Comparator
t_rise,oc,fast | 1e-06 | s | Trip time for fast overcurrent protection (3x overcurrent). 0.63*V_s = 1T
C_oc,fast | 1 | uF | Slow overcurrent protection timing cap.
R_oc,fast | 1 | Ohms
CR_oc,fast | 300 | % | Current Ratio for fast trip threshold.
I_oc,fast | 30 | A | Fast overcurrent trip threshold.
V_oc,fast | 4.40 | V | Trigger voltage for fast overcurrent protection.
R_oc,fast,in | 1 | kOhms | Input resistor value for fast overcurrent protection comparator.
V_oc,fast,tlh | 4.48 | V | Low high transition voltage for fast overcurrent protection.
V_oc,fast,thl | 4.33 | V | High low transition voltage for fast overcurrent protection.
V_oc,fast,ref | 4.35 | V
R_oc,fast,f | 34.06813627 | kOhms | Feedback resistor value for fast overcurrent protection comparator.
R_oc,ref,bot,fast | 66.8 | kOhms | Cap in parallel with bottom resistor in voltage sense divider for low pass filter.
Slow Overcurrent Protection Comparator
t_rise,oc,slow | 20 | s | Trip time for slow overcurrent protection (1.5x overcurrent).
C_oc,slow | 100 | uF
R_oc,slow | 200 | kOhms
CR_oc,slow | 150 | % | Current Ratio for slow trip ratio.
I_oc,slow | 15 | A | Slow overcurrent trip threshold.
V_oc,slow | 2.20 | V | Trigger voltage for slow overcurrent protection.
R_oc,slow,in | 1 | kOhms | Input resistor value for fast overcurrent protection comparator.
V_oc,slow,tlh | 2.27 | V | Low high transition voltage for fast overcurrent protection.
V_oc,slow,thl | 2.13 | V | High low transition voltage for fast overcurrent protection.
V_oc,slow,ref | 2.20 | V
R_oc,slow,f | 29.63026459 | kOhms | Feedback resistor value for fast overcurrent protection comparator.
R_oc,ref,bot,slow | 7.9 | kOhms | Corner frequency of voltage sense low pass filter.
Voltage Sense Parameters
Sense Divider
R_vsense,top | 19 | kOhms | Voltage sense divider top resistor.
R_vsense,bot | 1 | kOhms | Voltage sense divider bottom resistor.
C_vsense | 1 | uF | Voltage sense divider bottom filter capacitor.
f_vsense,c | 0.151 | kHz | Voltage sense divider corner frequency.
A_vsense | 0.05 | V/V | Voltage sense divider gain.
V_vsense,protection,th | 2.10 | V | Thresold voltage of voltage sense divider protection MOSFET (typical). Used values from 2N7002 datasheet (https://www.onsemi.com/pdf/datasheet/nds7002a-d.pdf). NOTE: make sure the MCU can handle voltages when MOSFET has minimum threshold voltage, and that sense range is not terribly impaced when MOSFET has maximum threshold voltage!
Undervoltage Protection Comparator
V_uvlo | 11 | V | Undervoltage lockout voltage. Set to satisfy acceptable minimum R_ds,on for PMOS switch in minimum supply voltage scenario, taking into account headroom required for PMOS drive circuit.
V_uvlo,div | 0.55 | V | Divided undervoltage lockout threshold.
V_uvlo,hysteresis | 1 | V | Hysteresis voltage (one side) of supply voltage for undervoltage lockout.
V_uvlo,top | 5 | V | Logic supply voltage for UVLO comparator circuit.
V_uvlo,div,tlh | 0.6 | V | Voltage sense divided voltage UVLO low to high transition voltage.
V_uvlo,div,thl | 0.5 | V | Voltage sense divided voltage UVLO high to low transition voltage.
R_uvlo,in | 1 | kOhms
V_uvlo,oh | 5 | V
R_uvlo,f | 50 | kOhms
V_uvlo,ref | 0.59 | V
V_TLH_CHECK | 0.60 | V
V_THL_CHECK | 0.5 | V
R_uvlo,ref,top | 10 | kOhms
R_uvlo,ref,bot | 1.3 | kOhms
Fault Latch
T_fault,latch | 1 | s | Desired RC latch time constant.
R_fault,latch | 10 | Mohms | Fault latch circuit timing cap discharge resistor.
C_fault,latch | 100 | nF | Fault latch circuit timing cap.

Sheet: Hysteresis Comparator
Symbol | Value | Units | Note
Non-Inverting Comparator with Hysteresis
V_TLH | 3 | V | Trigger voltage from low to high. | From MCP6543 Datasheet
V_THL | 2 | V | Trigger voltage from high to low.
R_1 | 10 | kOhms | Input resistance.
V_OH | 5 | V | Output voltage in high state.
R_F | 50 | kOhms
V_REF | 2.50 | V
V_TLH_CHECK | 3 | V
V_THL_CHECK | 2 | V
Inverting Comparator with Hysteresis
V_TLH | 2 | V
T_THL | 3 | V
R_1 | 10 | kOhms
V_OH | 5 | V
R_F | 40 | kOhms
V_REF | 2.5 | V
V_TLH_CHECK | 2
V_THL_CHECK | 3

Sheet: Temperature Ratings
Function | Component | Min Temp Rating | Max Temp Rating | Link | Note
Design Requirement |  | -40 | 70
MCU | STM32F446RCT6 | -40 | 85 | https://www.digikey.com/en/products/detail/stmicroelectronics/STM32F446RCT6TR/6621762 | Available as increased temp range variant with 105C max temp (STM32F446RCT7).
Comparator | MCP6541T-I/LT | -40 | 85 | https://www.digikey.com/en/products/detail/microchip-technology/MCP6541T-I-LT/551750
5V Power Supply Module | SPBW06F-05 | -40 | 85 | https://www.digikey.com/en/products/detail/microchip-technology/MCP6541T-I-LT/551750
Switch PMOS | SUD50P10-43L-GE3 | -55 | 175 | https://www.digikey.com/en/products/detail/vishay-siliconix/SUD50P10-43L-GE3/4563553 | Does not include derating due to operating current.
NPN Transistor | MMBT5551-7-F | -55 | 150 | https://www.digikey.com/en/products/detail/diodes-incorporated/MMBT5551-7-F/1154713
PNP Transistor | MMBT5401-7-F | -55 | 150 | https://www.digikey.com/en/products/detail/diodes-incorporated/MMBT5401-7-F/804878
Current Sense Amplifier | LTC6102HMS8#TRPBF | -40 | 125 | https://www.digikey.com/en/products/detail/analog-devices-inc/LTC6102HMS8-TRPBF/1746369
MCU Oscillator Crystal | FA-238 25.0000MB-K3 | -40 | 85 | https://support.epson.biz/td/api/doc_check.php?dl=brief_FA-238&lang=en
Polymer Capacitor | 16SVPC100M | -55 | 105 | https://industrial.panasonic.com/cdbs/www-data/pdf/AAB8000/AAB8000C256.pdf

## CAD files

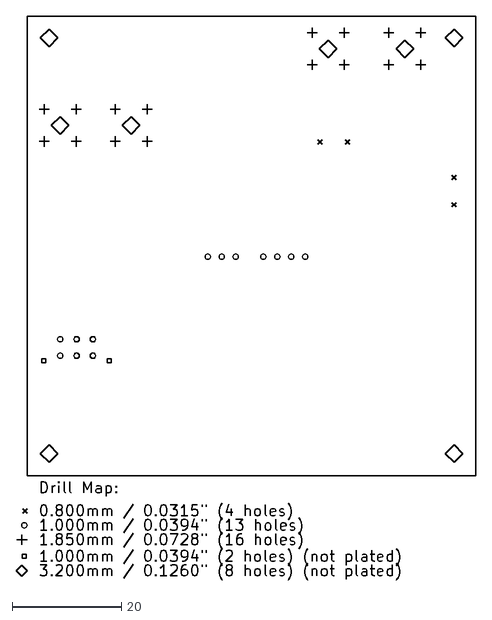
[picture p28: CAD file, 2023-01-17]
kicad/high_side_switch/plots/high_side_switch-drl_map.dxf
84.0 x 103.1

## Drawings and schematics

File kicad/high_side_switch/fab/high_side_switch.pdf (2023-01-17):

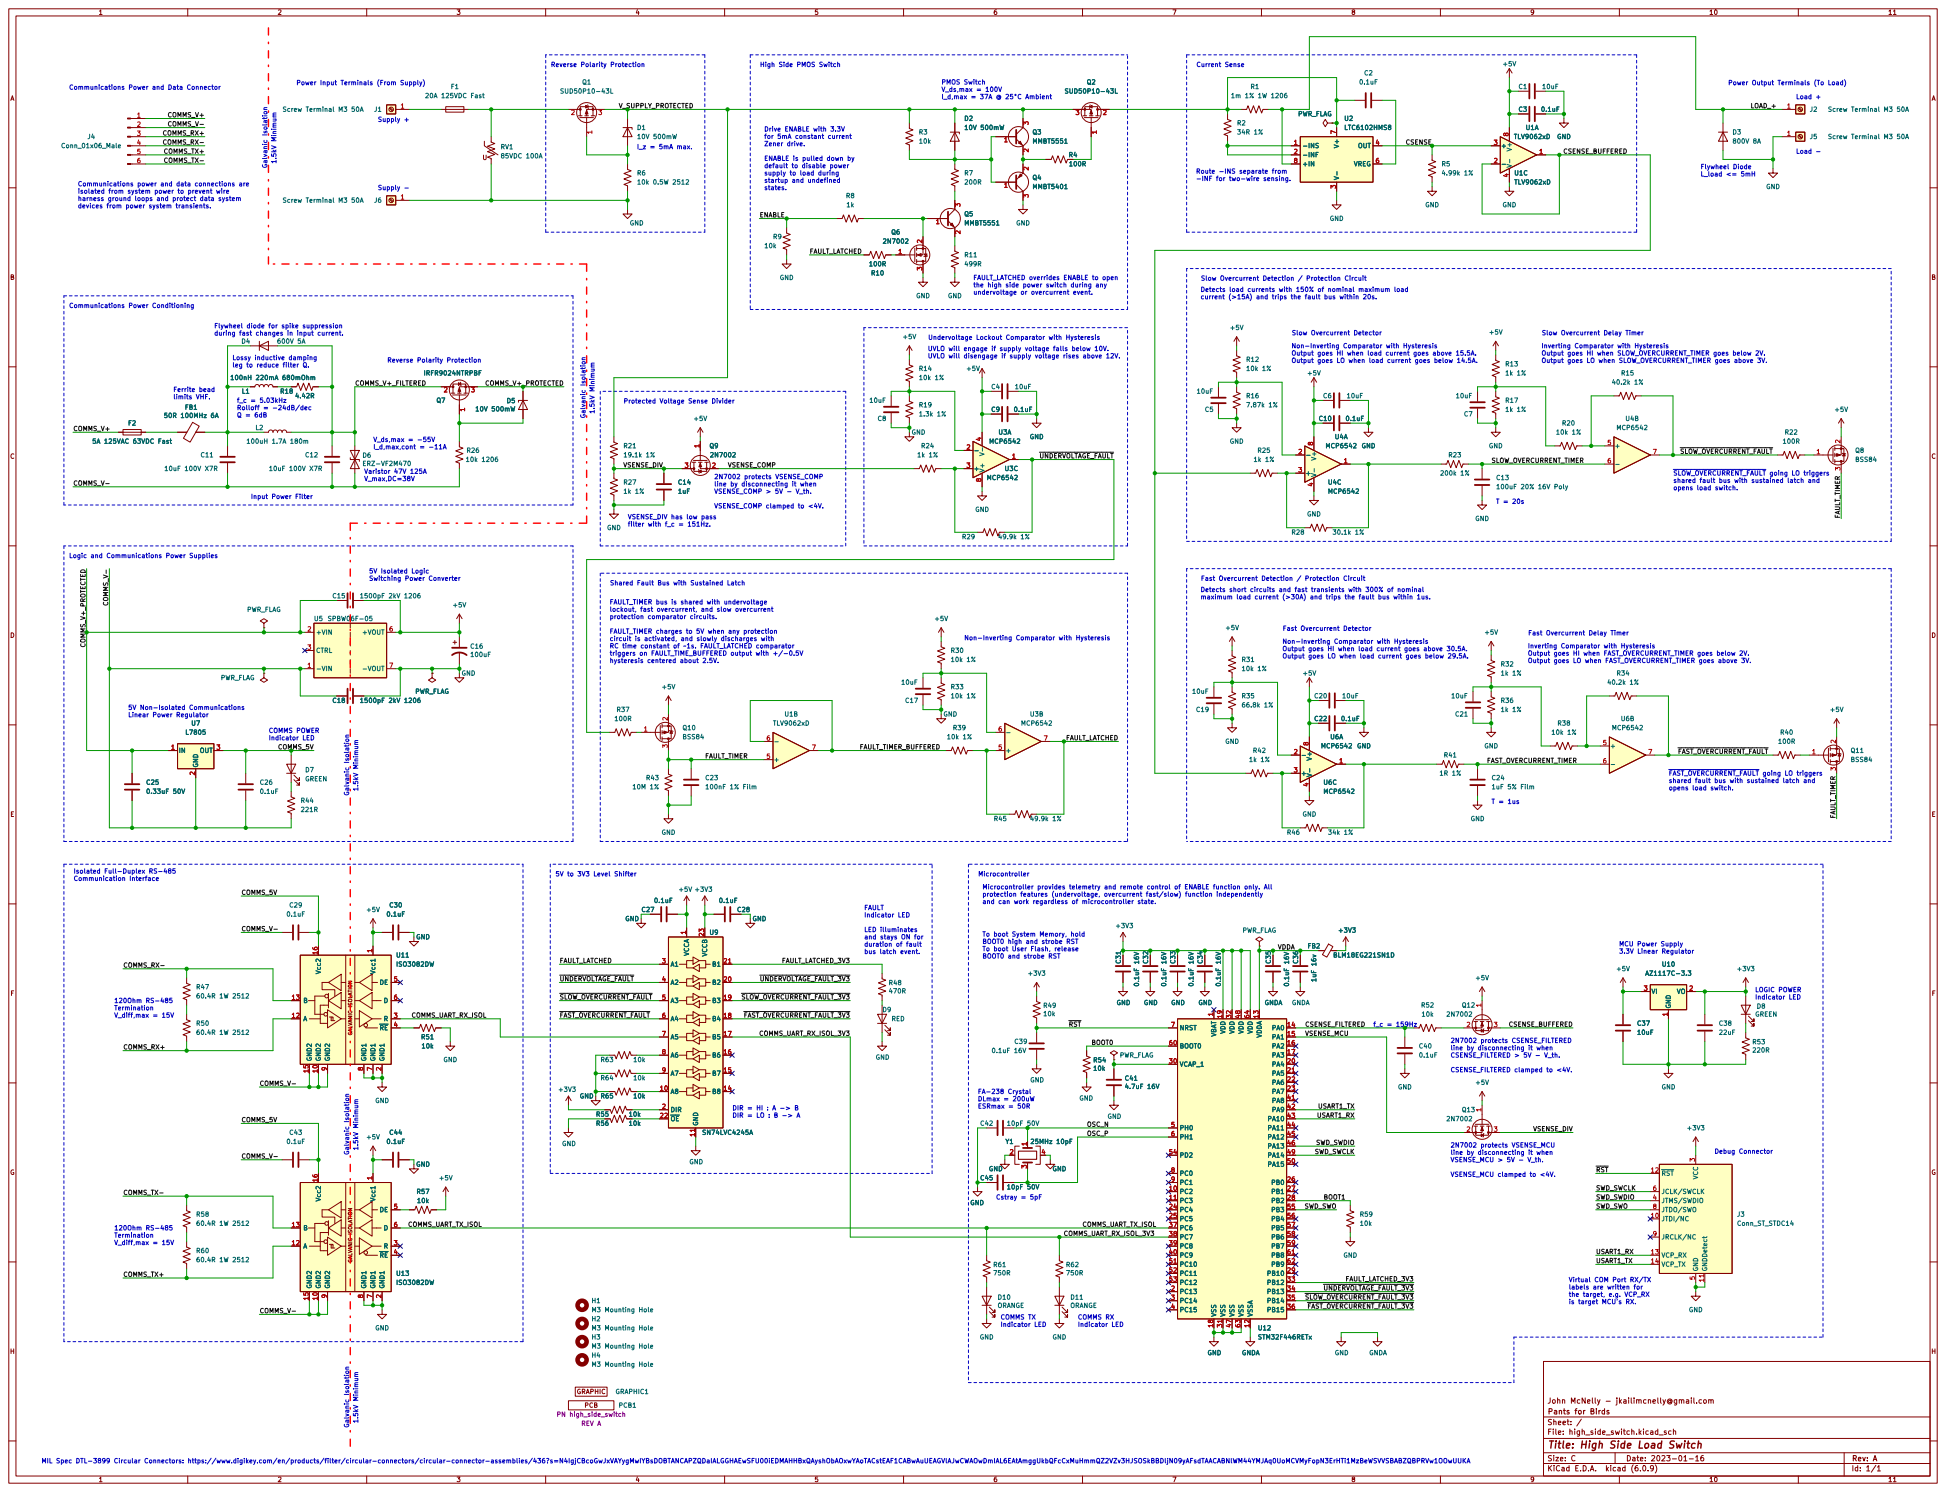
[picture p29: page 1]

-INF for two-wire sensing. Current Sense PMOS Switch V_ds,max = 100V

Power Output Terminals (To Load)

Indicator LED Galvanic Isolation

for 5mA constant current Zener drive. ENABLE is pulled down by

Load - Route -INS separate from

default to disable power
supply to load during
startup and undefined

Communications power and data connections are
isolated from system power to prevent wire
harness ground loops and protect data system

FAULT_LATCHED overrides ENABLE to open
the high side power switch during any

Output goes LO when load current goes below 14.5A. Slow Overcurrent Detection / Protection Circuit Fast Overcurrent Detection / Protection Circuit Detects short circuits and fast transients with 300% of nominal maximum load current (>30A) and trips the fault bus within 1us. U6A MCP6542
Detects load currents with 150% of nominal maximum load
current (>15A) and trips the fault bus within 20s. Slow Overcurrent Detector

Communications Power Conditioning
limits VHF. 5V Non-Isolated Communications Linear Power Regulator

Flywheel diode for spike suppression
during fast changes in input current.

Slow Overcurrent Delay Timer
Inverting Comparator with Hysteresis
Output goes HI when SLOW_OVERCURRENT_TIMER goes below 2V.
Output goes LO when SLOW_OVERCURRENT_TIMER goes above 3V.

Undervoltage Lockout Comparator with Hysteresis
UVLO will engage if supply voltage falls below 10V.
UVLO will disengage if supply voltage rises above 12V.

Non-Inverting Comparator with Hysteresis
Output goes HI when load current goes above 15.5A.

filter with f_c = 151Hz. Reverse Polarity Protection Varistor 47V 125A

2N7002 protects VSENSE_COMP
line by disconnecting it when VSENSE_COMP > 5V - V_th. VSENSE_COMP clamped to <4V.

shared fault bus with sustained latch and
opens load switch.

Logic and Communications Power Supplies

Switching Power Converter COMMS POWER

Shared Fault Bus with Sustained Latch

FAULT_TIMER bus is shared with undervoltage
lockout, fast overcurrent, and slow overcurrent protection comparator circuits.

Fast Overcurrent Delay Timer T = 1us Fast Overcurrent Detector

FAULT_TIMER charges to 5V when any protection
circuit is activated, and slowly discharges with
RC time constant of ~1s. FAULT_LATCHED comparator
triggers on FAULT_TIME_BUFFERED output with +/-0.5V
hysteresis centered about 2.5V.

Output goes HI when FAST_OVERCURRENT_TIMER goes below 2V.
Output goes LO when FAST_OVERCURRENT_TIMER goes above 3V.

Output goes HI when load current goes above 30.5A.
Output goes LO when load current goes below 29.5A.

~{FAST_OVERCURRENT_FAULT} going LO triggers

Microcontroller To boot System Memory, hold
ESRmax = 50R Microcontroller provides telemetry and remote control of ENABLE function only. All
protection features (undervoltage, overcurrent fast/slow) function independently
and can work regardless of microcontroller state.

1 A8 10 GND 11 B8 14 B7 15 B6 16 B5 17 B4 18 B3 19 DIR 2 B2 20 B1 21 ~{OE} 22 VCCB 23 A1 3 A2 4 A3 5 A4 6 A5 7 A6 8 A7 9 GND

1 A8 10 GND 11 B8 14 B7 15 B6 16 B5 17 B4 18 B3 19 DIR 2 B2 20 B1 21 ~{OE} 22 VCCB 23 A1 3 A2 4 A3 5 A4 6 A5 7 A6 8 A7 9 U9 SN74LVC4245A

BOOT0 high and strobe RST
To boot User Flash, release BOOT0 and strobe RST

2N7002 protects CSENSE_FILTERED
line by disconnecting it when CSENSE_FILTERED > 5V - V_th. CSENSE_FILTERED clamped to <4V.

2N7002 protects VSENSE_MCU
line by disconnecting it when VSENSE_MCU > 5V - V_th. VSENSE_MCU clamped to <4V.

is target MCU's RX. 120Ohm RS-485 Termination V_diff,max = 15V

Virtual COM Port RX/TX
labels are written for
the target, e.g. VCP_RX

John McNelly - jkailimcnelly@gmail.com
File: high_side_switch.kicad_sch Sheet: / Pants for Birds

Id: 1/1 Title: High Side Load Switch

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

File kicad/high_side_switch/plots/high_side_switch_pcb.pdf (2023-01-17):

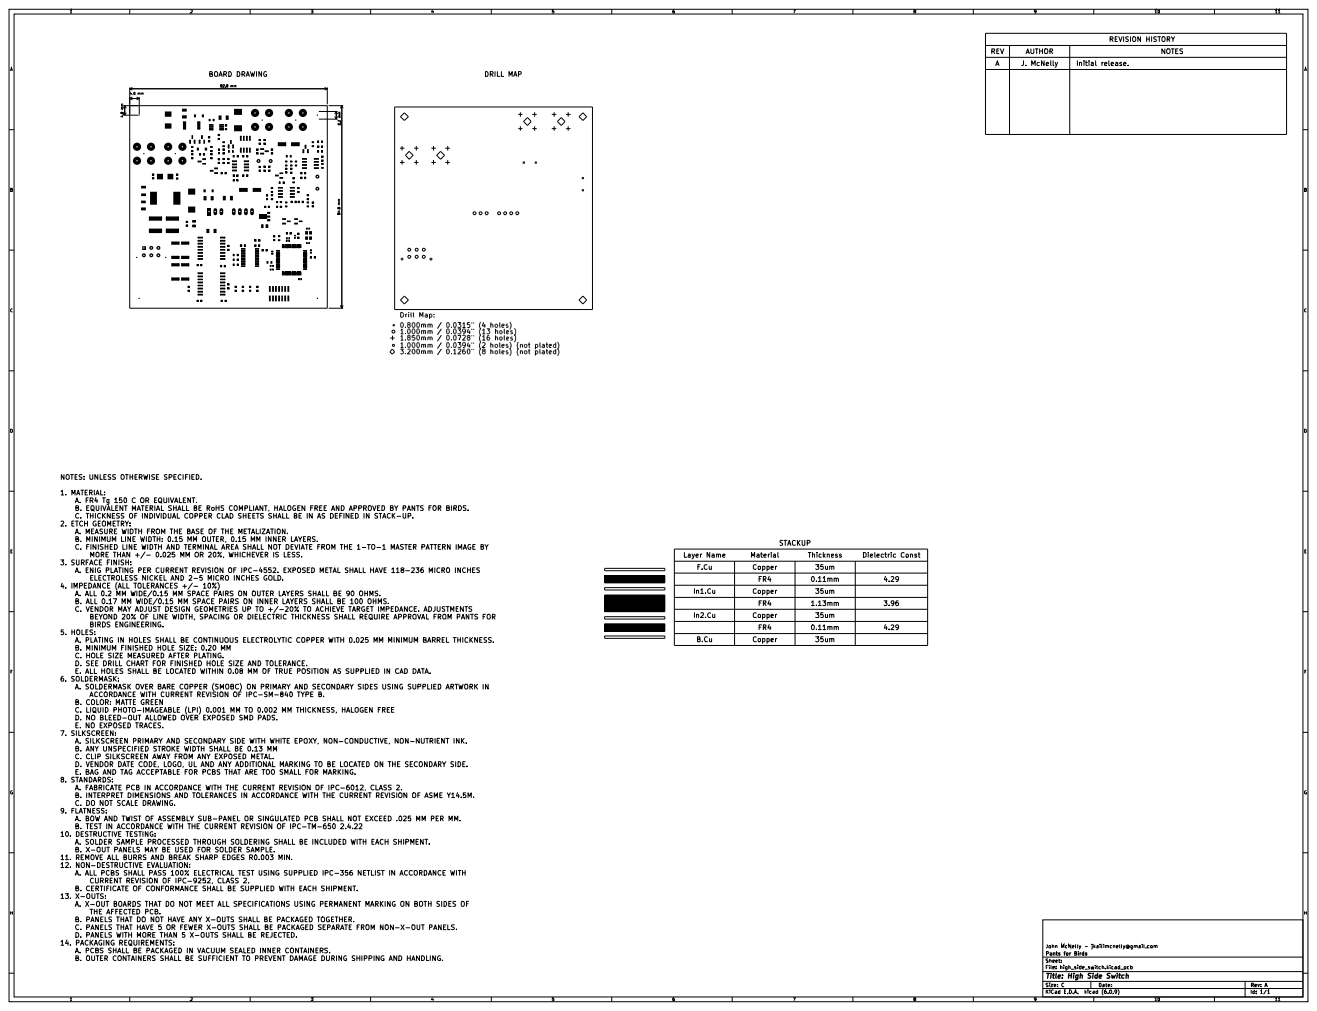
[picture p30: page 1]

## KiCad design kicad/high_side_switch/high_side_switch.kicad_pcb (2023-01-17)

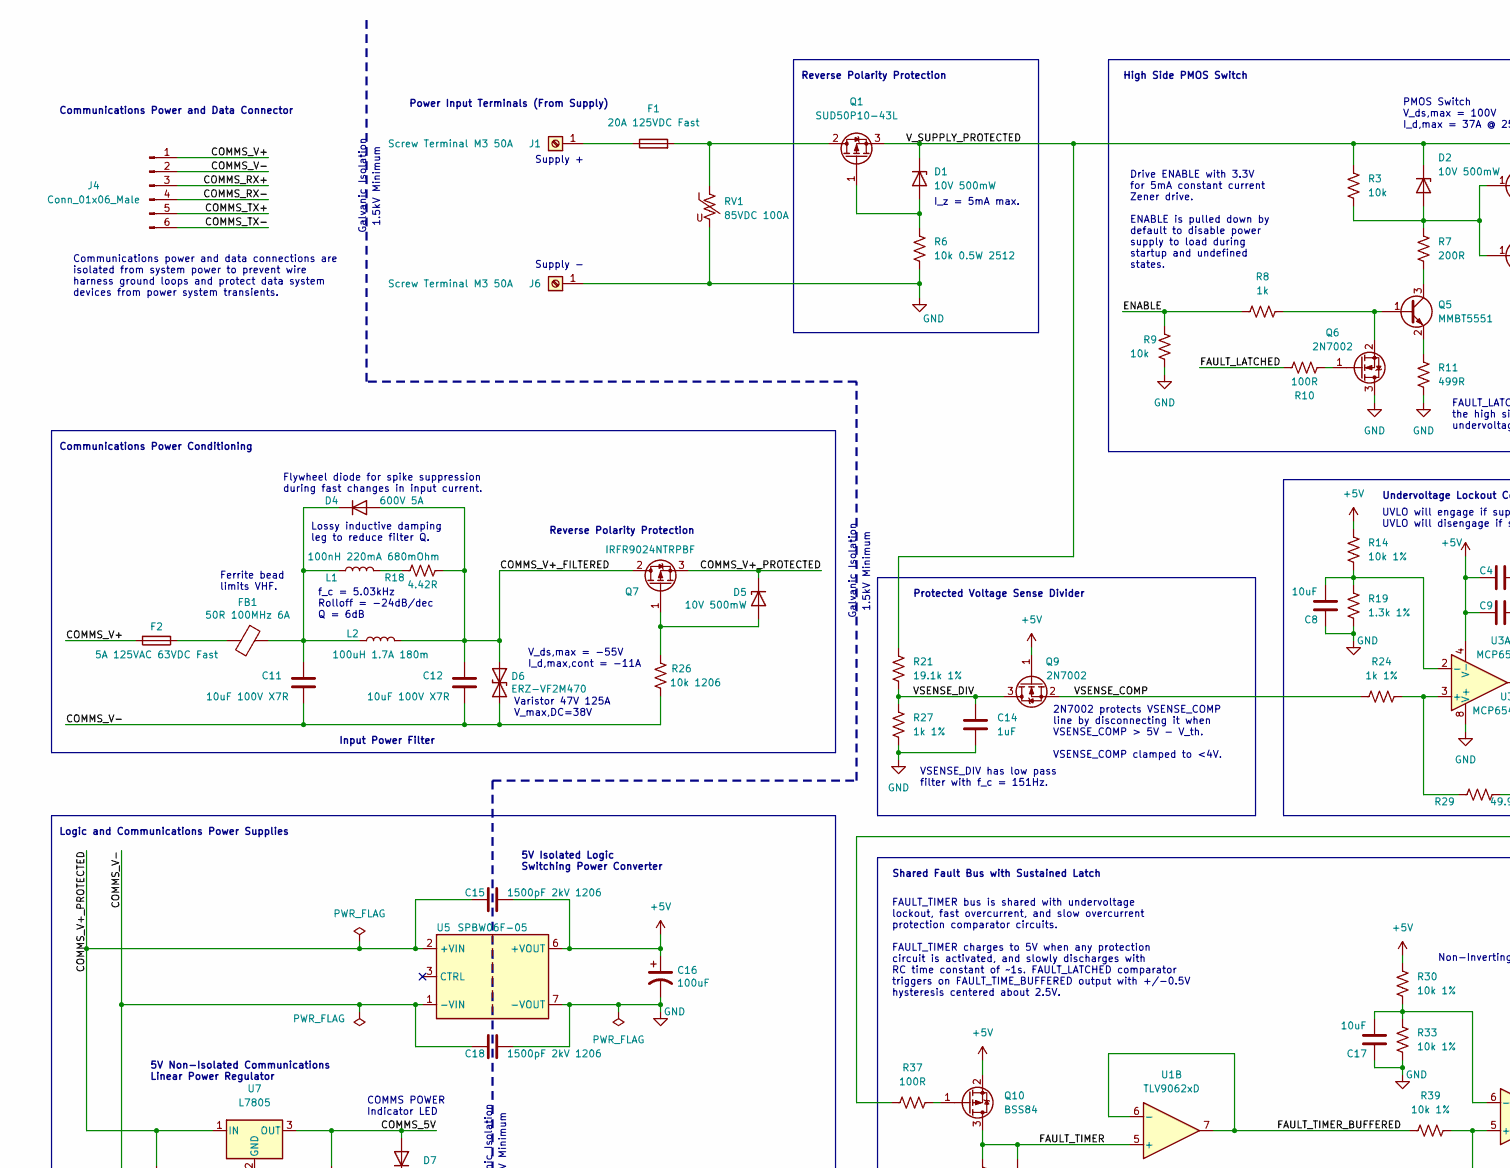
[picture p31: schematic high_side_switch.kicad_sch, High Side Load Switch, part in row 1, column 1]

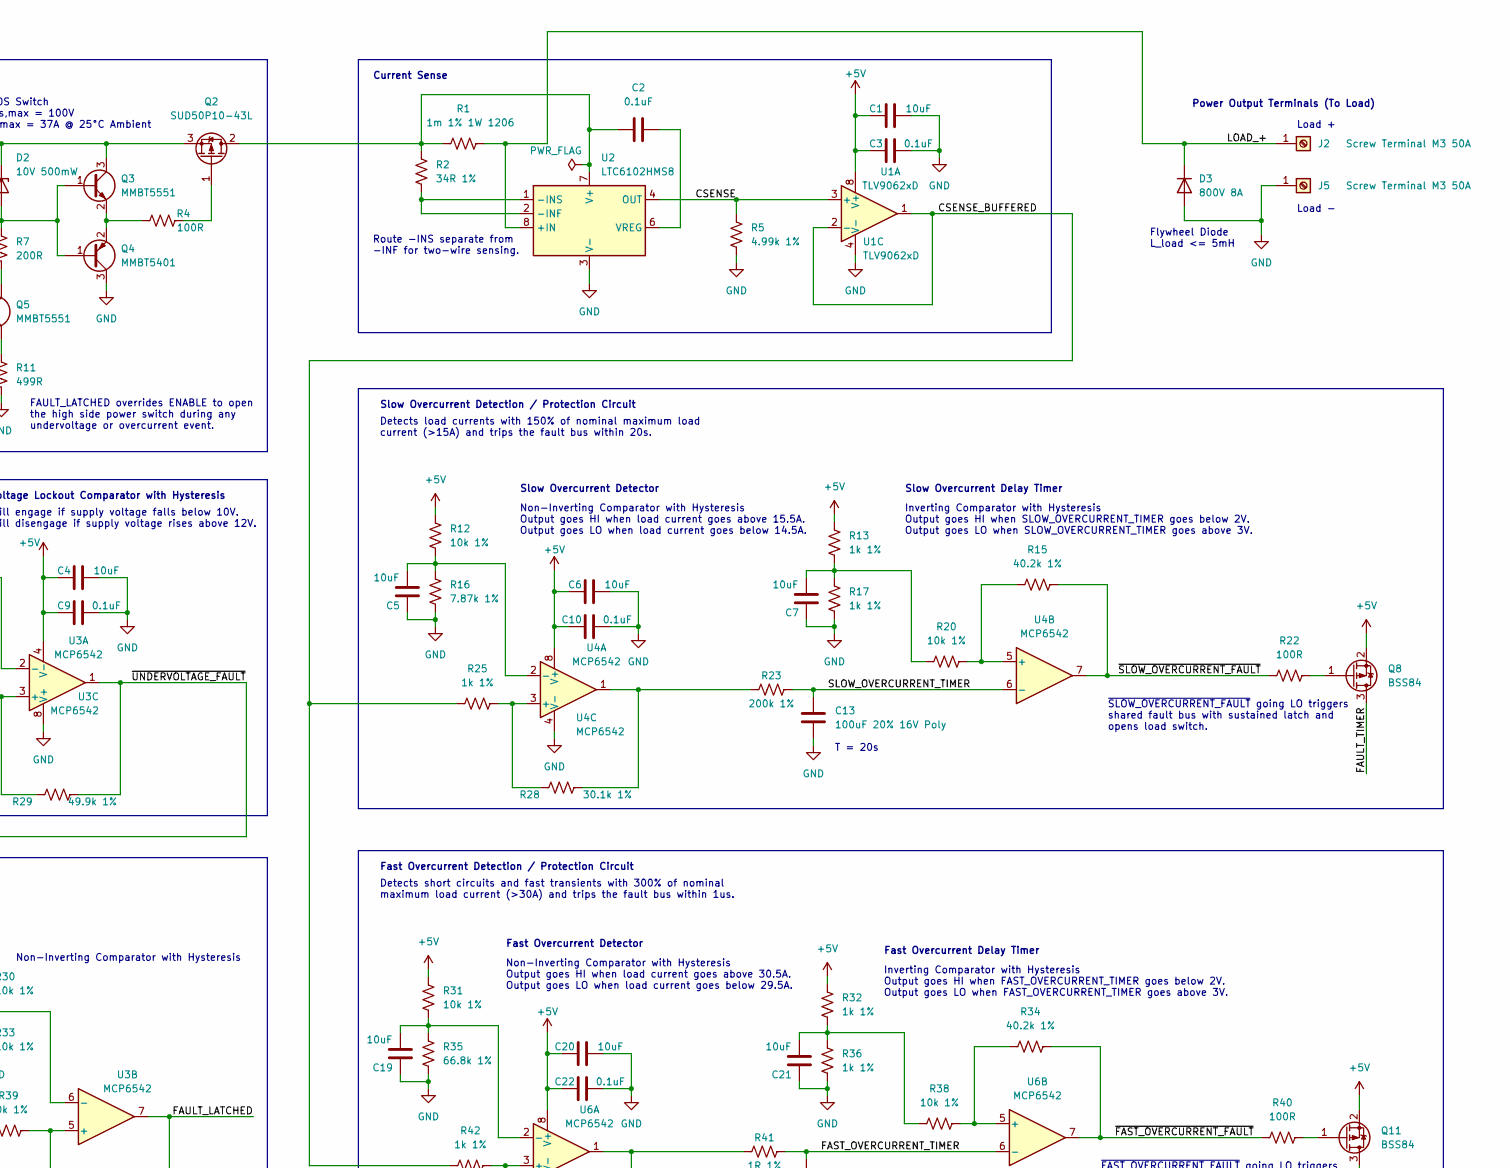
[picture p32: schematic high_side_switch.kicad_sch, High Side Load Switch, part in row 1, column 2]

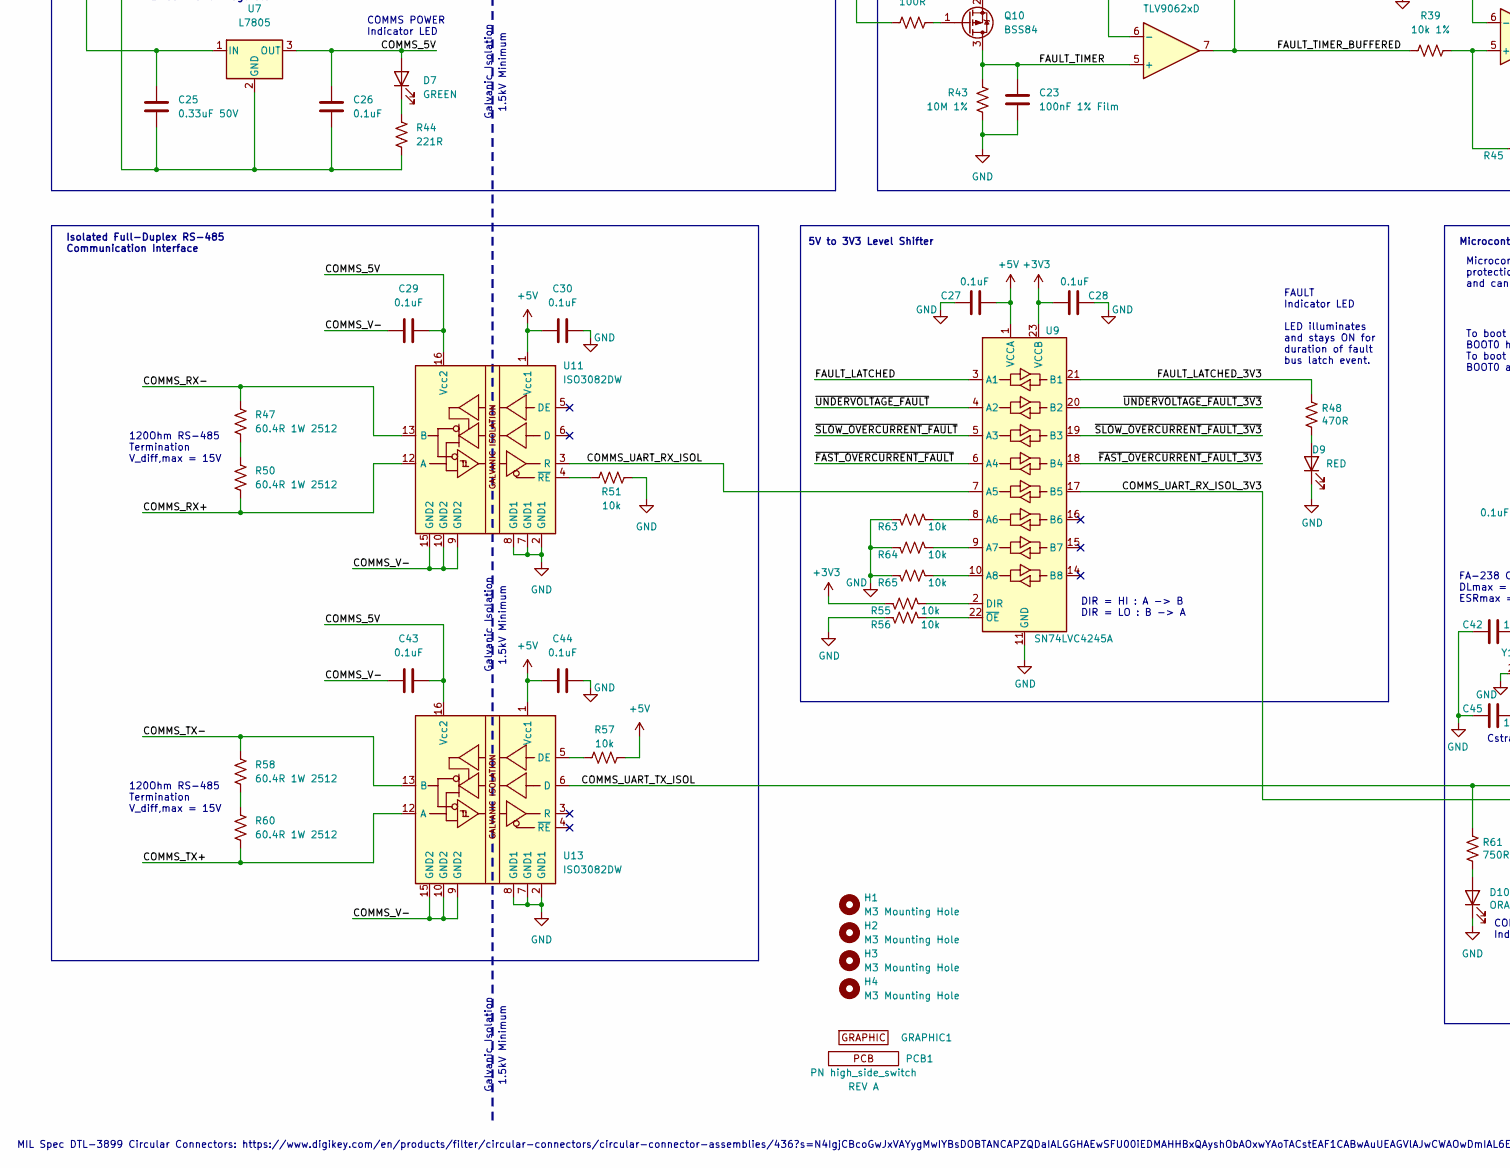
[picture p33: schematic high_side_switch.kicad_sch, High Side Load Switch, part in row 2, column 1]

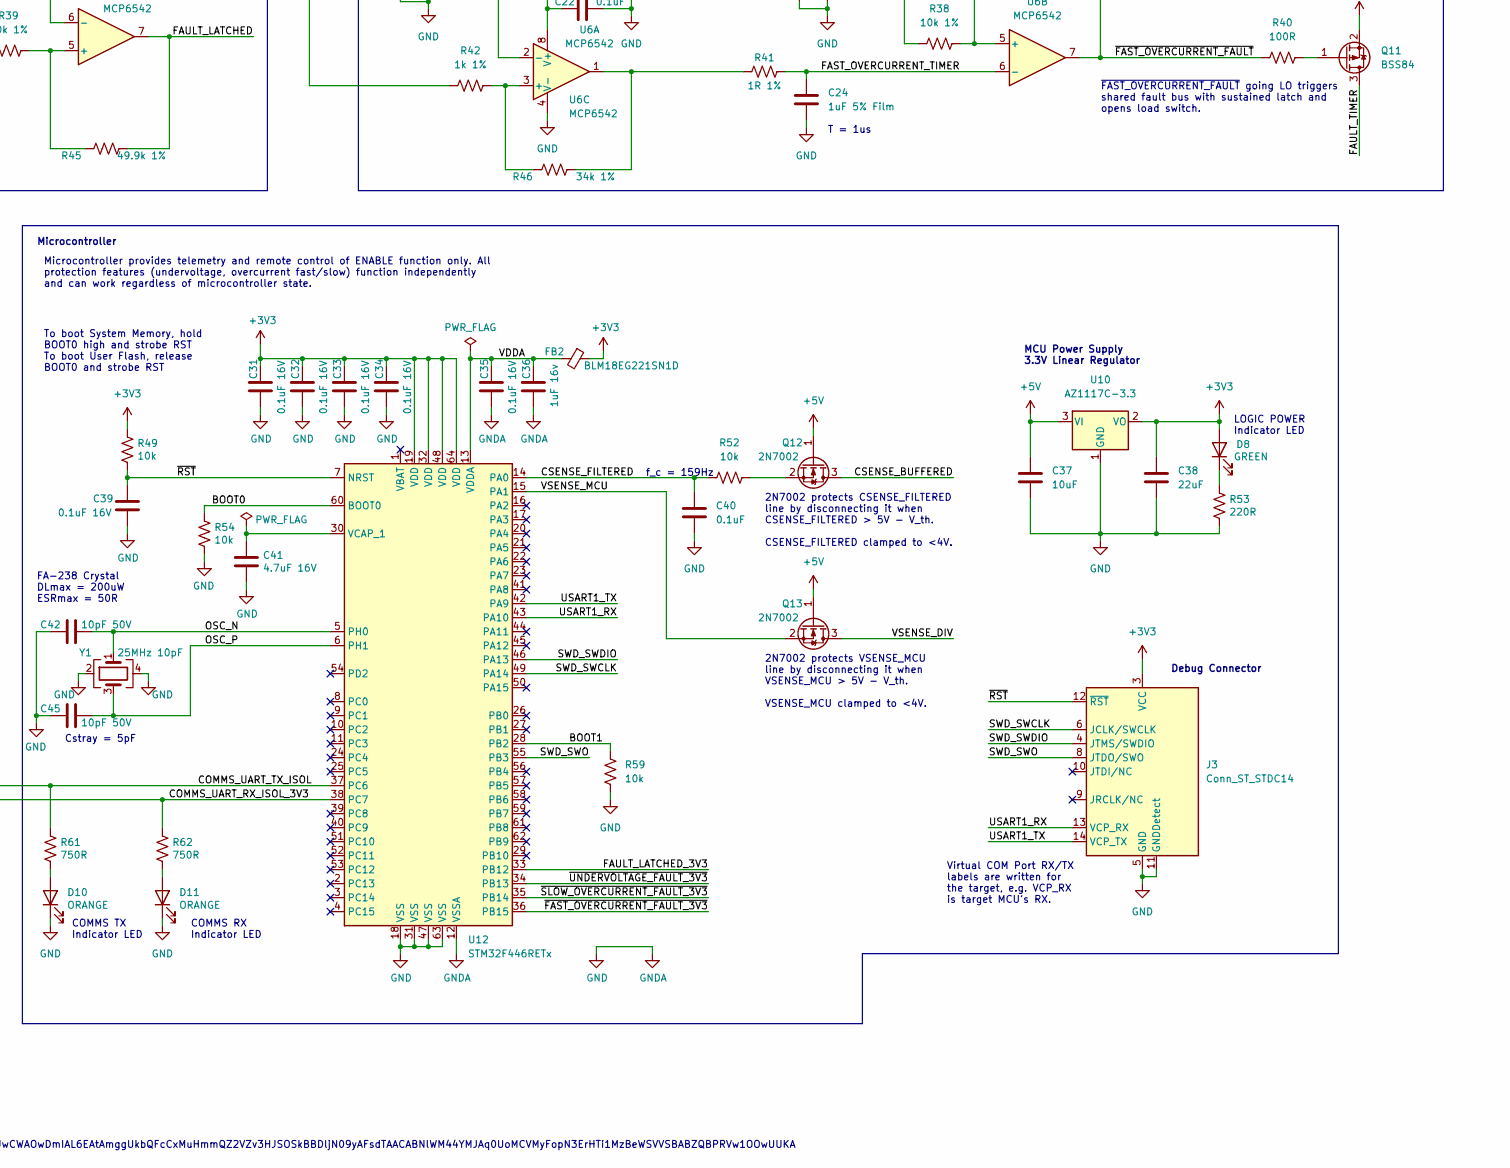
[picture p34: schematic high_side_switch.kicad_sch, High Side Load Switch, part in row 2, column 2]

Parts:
C1, C4, C5, C6, C7, C8, C17, C19, C20, C21, C37: 10uF; C_0603_1608Metric
C2, C3, C9, C10, C22, C26, C29, C30, C40, C43, C44: 0.1uF; C_0603_1608Metric
C11, C12: 10uF 100V X7R; C_2220_5650Metric; MPN 22201C106MAT2A
C13: 100uF 20% 16V Poly; CP_Elec_6.3x5.9; MPN 16SVPC100M
C14: 1uF; C_0603_1608Metric
C15, C18: 1500pF 2kV 1206; C_1206_3216Metric; MPN C1206C152KGRACAUTO
C16: 100uF; CP_Elec_6.3x5.9; MPN 16SVPC100M
C23: 100nF 1% Film; C_Rect_L7.2mm_W2.5mm_P5.00mm_FKS2_FKP2_MKS2_MKP2; MPN R82DC3100DQ50J
C24: 1uF 5% Film; C_Rect_L7.2mm_W5.5mm_P5.00mm_FKS2_FKP2_MKS2_MKP2; MPN R82EC4100DQ70J
C25: 0.33uF 50V; C_0805_2012Metric
C27, C28: 0.1uF; C_0603_1608Metric; MPN CL10B104MB8NNNC
C31, C32, C33, C34, C35, C39: 0.1uF 16V; C_0402_1005Metric; MPN CL05B104KO5NNNC
C36: 1uF 16v; C_0402_1005Metric; MPN CL05A105KO5NNNC
C38: 22uF; C_0805_2012Metric
C41: 4.7uF 16V; C_0402_1005Metric; MPN CL05A475MO5NUNC
C42, C45: 10pF 50V; C_0402_1005Metric; MPN CC0402JRNPO9BN100
D1, D2, D5: 10V 500mW; D_SOD-123; MPN BZT52C10-7-F
D3: 800V 8A; D_SMC; MPN S8KC-13
D4: 600V 5A; D_SMB; MPN SD560BTR
D6: ERZ-VF2M470; Panasonic_ZNR-VF; MPN ERZ-VF2M470
D7, D8: GREEN; LED_0603_1608Metric; MPN SML-D13M8WT86
D9: RED; LED_0603_1608Metric; MPN SML-D12U8WT86
D10, D11: ORANGE; LED_0603_1608Metric; MPN SML-D12D8WT86
F1: 20A 125VDC Fast; Fuse_BelFuse_0679L; MPN 0679L9200-05
F2: 5A 125VAC 63VDC Fast; R_1206_3216Metric; MPN C1Q 5
FB1: 50R 100MHz 6A; L_1206_3216Metric; MPN 2512065007Y6
FB2: BLM18EG221SN1D; L_0603_1608Metric; MPN BLM18EG221SN1D
GRAPHIC1: Graphic; bird_with_pants_small_flipped
H1, H2, H3, H4: M3 Mounting Hole; MountingHole_3.2mm_M3
J1, J2, J5, J6: Screw Terminal M3 50A; Wuerth_Redcube_74650073R_M3; MPN 74650073R
J3: Conn_ST_STDC14; PinHeader_2x07_P1.27mm_Vertical_SMD; MPN FTSH-107-01-L-DV-K
J4: Conn_01x06_Male; Molex_Micro-Fit_3.0_43045-0612_2x03_P3.00mm_Vertical; MPN 0430450612
L1: 100nH 220mA 680mOhm; L_0603_1608Metric; MPN LQW18ANR10J00D
L2: 100uH 1.7A 180m; L_Bourns_SRR1260; MPN SRR1260-101M
PCB1: PCB; PCB_PN_REV; MPN PN high_side_switch
Q1, Q2: SUD50P10-43L; TO-252-3_TabPin2; MPN SUD50P10-43L-GE3
Q3, Q5: MMBT5551; SOT-23; MPN MMBT5551-7-F
Q4: MMBT5401; SOT-23; MPN MMBT5401-7-F
Q6, Q9, Q12, Q13: 2N7002; SOT-23
Q7: IRFR9024NTRPBF; TO-252-2; MPN IRFR9024NTRPBF
Q8, Q10, Q11: BSS84; SOT-23
R1: 1m 1% 1W 1206; R_1206_3216Metric; MPN CSNL1206FT1L00
R2: 34R 1%; R_0603_1608Metric
R3, R9, R49, R51, R52, R54, R57, R59: 10k; R_0603_1608Metric
R4, R10, R22, R37, R40: 100R; R_0603_1608Metric
R5: 4.99k 1%; R_0603_1608Metric
R6: 10k 0.5W 2512; R_2512_6332Metric
R7: 200R; R_0603_1608Metric
R8: 1k; R_0603_1608Metric
R11: 499R; R_0603_1608Metric
R12, R14, R20, R30, R31, R33, R38, R39: 10k 1%; R_0603_1608Metric
R13, R17, R24, R25, R27, R32, R36, R42: 1k 1%; R_0603_1608Metric
R15, R34: 40.2k 1%; R_0603_1608Metric
R16: 7.87k 1%; R_0603_1608Metric
R18: 4.42R; R_0603_1608Metric; MPN RC0603FR-074R42L
R19: 1.3k 1%; R_0603_1608Metric
R21: 19.1k 1%; R_0603_1608Metric
R23: 200k 1%; R_0603_1608Metric
R26: 10k 1206; R_1206_3216Metric; MPN RC1206FR-0710KL
R28: 30.1k 1%; R_0603_1608Metric
R29, R45: 49.9k 1%; R_0603_1608Metric
R35: 66.8k 1%; R_0603_1608Metric
R41: 1R 1%; R_0603_1608Metric
R43: 10M 1%; R_0603_1608Metric
R44: 221R; R_0603_1608Metric
R46: 34k 1%; R_0603_1608Metric
R47, R50, R58, R60: 60.4R 1W 2512; R_2512_6332Metric; MPN RMCF2512FT60R4
R48: 470R; R_0603_1608Metric
R53: 220R; R_0603_1608Metric
R55, R56, R63, R64, R65: 10k; R_0603_1608Metric; MPN RC0603FR-0710KL
R61, R62: 750R; R_0603_1608Metric
RV1: 85VDC 100A; Fuse_1206_3216Metric; MPN B72520T0600K062
U1: TLV9062xD; SOIC-8_3.9x4.9mm_P1.27mm
U2: LTC6102HMS8; MSOP-8_3x3mm_P0.65mm; MPN LTC6102HMS8#TRPBF
U3, U4, U6: MCP6542; SOIC-8_3.9x4.9mm_P1.27mm; MPN MCP6542T-I/SN
U5: SPBW06F-05; Converter_DCDC_TRACO_TMR-xxxx_THT; MPN SPBW06F-05
U7: L7805; TO-252-3_TabPin2; MPN L7805ABD2T-TR
U9: SN74LVC4245A; TSSOP-24_4.4x7.8mm_P0.65mm; MPN SN74LVC4245APWR
U10: AZ1117C-3.3; SOT-89-3; MPN AZ1117CR-3.3TRG1
U11, U13: ISO3082DW; SOIC-16W_7.5x10.3mm_P1.27mm; MPN ISO3082DWR
U12: STM32F446RETx; LQFP-64_10x10mm_P0.5mm; MPN STM32F446RET6
Y1: 25MHz 10pF; Crystal_SMD_SeikoEpson_FA238-4Pin_3.2x2.5mm; MPN FA-238 25.0000MB-K3

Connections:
+3V3: C28.2, C31.1, C32.1, C33.1, C34.1, C38.1, D8.2 (A), FB2.1, J3.3 (VCC), R49.1, R55.1, U9.23 (VCCB), U9.24 (VCCB), U10.2 (VO), U12.19 (VDD), U12.32 (VDD), U12.48 (VDD), U12.64 (VDD)
+5V: C1.1, C3.1, C4.1, C6.1, C9.1, C10.1, C15.2, C16.1, C20.1, C22.1, C27.2, C30.1, C37.1, C44.1, Q8.2 (S), Q9.1 (G), Q10.2 (S), Q11.2 (S), Q12.1 (G), Q13.1 (G), R12.1, R13.1, R14.1, R30.1, R31.1, R32.1, R57.2, U1.8 (V+), U3.4 (V-), U4.8 (V+), U5.6 (+VOUT), U6.8 (V+), U9.1 (VCCA), U10.3 (VI), U11.1 (Vcc1), U13.1 (Vcc1)
/BOOT0: R54.1, U12.60 (BOOT0)
/BOOT1: R59.1, U12.28 (PB2)
/COMMS_5V: C26.1, C29.2, C43.2, D7.2 (A), U7.3 (OUT), U11.16 (Vcc2), U13.16 (Vcc2)
/COMMS_RX+: J4.3, R50.2, U11.12 (A)
/COMMS_RX-: J4.4, R47.1, U11.13 (B)
/COMMS_TX+: J4.5, R60.2, U13.12 (A)
/COMMS_TX-: J4.6, R58.1, U13.13 (B)
/COMMS_UART_RX_ISOL: U9.7 (A5), U11.3 (R)
/COMMS_UART_RX_ISOL_3V3: R62.1, U9.17 (B5), U12.38 (PC7)
/COMMS_UART_TX_ISOL: R61.1, U12.37 (PC6), U13.6 (D)
/COMMS_V+: F2.2, J4.1
/COMMS_V+_FILTERED: C12.1, D4.2 (A), D6.1 (A1), L2.2, Q7.2 (D), R18.1
/COMMS_V+_PROTECTED: C15.1, C25.1, D5.1 (K), Q7.3 (S), U5.2 (+VIN), U7.1 (IN)
/COMMS_V-: C11.2, C12.2, C18.1, C25.2, C26.2, C29.1, C43.1, D6.2 (A2), J4.2, R26.1, R44.2, U5.1 (-VIN), U7.2 (GND), U11.9 (GND2), U11.10 (GND2), U11.15 (GND2), U13.9 (GND2), U13.10 (GND2), U13.15 (GND2)
/CSENSE: R5.1, U1.3 (+), U2.4 (OUT)
/CSENSE_BUFFERED: Q12.3 (D), R25.1, R42.1, U1.1, U1.2 (-)
/CSENSE_FILTERED: C40.1, R52.1, U12.14 (PA0)
/ENABLE: R8.1, R9.1
/FAST_OVERCURRENT_TIMER: C24.1, R41.2, U6.6 (-)
/FAULT_LATCHED: R10.1, R45.2, U3.7, U9.3 (A1)
/FAULT_LATCHED_3V3: R48.1, U9.21 (B1), U12.33 (PB12)
/FAULT_TIMER: C23.1, Q8.3 (D), Q10.3 (D), Q11.3 (D), R43.1, U1.5 (+)
/FAULT_TIMER_BUFFERED: R39.1, U1.6 (-), U1.7
/LOAD_+: D3.1 (K), J2.1, R1.2, U2.8 (+IN)
/OSC_N: C42.2, U12.5 (PH0), Y1.1
/OSC_P: C45.2, U12.6 (PH1), Y1.3
/SLOW_OVERCURRENT_TIMER: C13.1, R23.2, U4.6 (-)
/SWD_SWCLK: J3.6 (JCLK/SWCLK), U12.49 (PA14)
/SWD_SWDIO: J3.4 (JTMS/SWDIO), U12.46 (PA13)
/SWD_SWO: J3.8 (JTDO/SWO), U12.55 (PB3)
/USART1_RX: J3.13 (VCP_RX), U12.43 (PA10)
/USART1_TX: J3.14 (VCP_TX), U12.42 (PA9)
/VDDA: C35.1, C36.1, FB2.2, U12.13 (VDDA)
/VSENSE_COMP: Q9.2 (S), R24.1
/VSENSE_DIV: C14.1, Q9.3 (D), Q13.3 (D), R21.2, R27.1
/VSENSE_MCU: Q13.2 (S), U12.15 (PA1)
/V_SUPPLY_PROTECTED: D1.1 (K), D2.1 (K), Q1.3 (S), Q2.3 (S), Q3.3 (C), R3.1, R21.1
/~FAST_OVERCURRENT_FAULT_3V3: U9.18 (B4), U12.36 (PB15)
/~FAST_OVERCURRENT_FAULT: R34.2, R40.1, U6.7, U9.6 (A4)
/~RST: C39.1, J3.12 (~RST), R49.2, U12.7 (NRST)
/~SLOW_OVERCURRENT_FAULT_3V3: U9.19 (B3), U12.35 (PB14)
/~SLOW_OVERCURRENT_FAULT: R15.2, R22.1, U4.7, U9.5 (A3)
/~UNDERVOLTAGE_FAULT_3V3: U9.20 (B2), U12.34 (PB13)
/~UNDERVOLTAGE_FAULT: R29.2, R37.1, U3.1, U9.4 (A2)
GND: C1.2, C3.2, C4.2, C5.1, C6.2, C7.1, C8.1, C9.2, C10.2, C13.2, C14.2, C16.2, C17.1, C18.2, C19.1, C20.2, C21.1, C22.2, C23.2, C24.2, C27.1, C28.1, C30.2, C31.2, C32.2, C33.2, C34.2, C35.2, C36.2, C37.2, C38.2, C39.2, C40.2, C41.2, C42.1, C44.2, C45.1, D3.2 (A), D9.1 (K), D10.1 (K), D11.1 (K), J3.5 (GND), J3.7 (GND), J3.11 (GNDDetect), J5.1, J6.1, Q4.3 (C), Q6.3 (D), R5.2, R6.2, R9.2, R11.2, R16.2, R17.2, R19.2, R27.2, R33.2, R35.2, R36.2, R43.2, R51.2, R53.2, R54.2, R56.1, R59.2, R63.1, R64.1, R65.1, RV1.2, U1.4 (V-), U2.3 (V-), U2.5 (V-), U3.8 (V+), U4.4 (V-), U5.7 (-VOUT), U6.4 (V-), U9.11 (GND), U9.12 (GND), U9.13 (GND), U10.1 (GND), U11.2 (GND1), U11.7 (GND1), U11.8 (GND1), U12.12 (VSSA), U12.18 (VSS), U12.31 (VSS), U12.47 (VSS), U12.63 (VSS), U13.2 (GND1), U13.7 (GND1), U13.8 (GND1), Y1.2, Y1.4
unnamed: C2.1, Q2.2 (D), R1.1, R2.1, U2.7 (V+)
unnamed: C2.2, U2.6 (VREG)
unnamed: C5.2, R12.2, R16.1, U4.2 (-)
unnamed: C7.2, R13.2, R17.1, R20.1
unnamed: C8.2, R14.2, R19.1, U3.2 (-)
unnamed: C11.1, D4.1 (K), FB1.1, L1.1, L2.1
unnamed: C17.2, R30.2, R33.1, U3.6 (-)
unnamed: C19.2, R31.2, R35.1, U6.2 (-)
unnamed: C21.2, R32.2, R36.1, R38.1
unnamed: C41.1, U12.30 (VCAP_1)
unnamed: D1.2 (A), Q1.1 (G), R6.1
unnamed: D2.2 (A), Q3.1 (B), Q4.1 (B), R3.2, R7.1
unnamed: D5.2 (A), Q7.1 (G), R26.2
unnamed: D7.1 (K), R44.1
unnamed: D8.1 (K), R53.1
unnamed: D9.2 (A), R48.2
unnamed: D10.2 (A), R61.2
unnamed: D11.2 (A), R62.2
unnamed: F1.1, J1.1
unnamed: F1.2, Q1.2 (D), RV1.1
unnamed: F2.1, FB1.2
unnamed: L1.2, R18.2
unnamed: Q2.1 (G), R4.2
unnamed: Q3.2 (E), Q4.2 (E), R4.1
unnamed: Q5.1 (B), Q6.2 (S), R8.2
unnamed: Q5.2 (E), R11.1
unnamed: Q5.3 (C), R7.2
unnamed: Q6.1 (G), R10.2
unnamed: Q8.1 (G), R22.2
unnamed: Q10.1 (G), R37.2
unnamed: Q11.1 (G), R40.2
unnamed: Q12.2 (S), R52.2
unnamed: R2.2, U2.1 (-INS), U2.2 (-INF)
unnamed: R15.1, R20.2, U4.5 (+)
unnamed: R23.1, R28.2, U4.1
unnamed: R24.2, R29.1, U3.3 (+)
unnamed: R25.2, R28.1, U4.3 (+)
unnamed: R34.1, R38.2, U6.5 (+)
unnamed: R39.2, R45.1, U3.5 (+)
unnamed: R41.1, R46.2, U6.1
unnamed: R42.2, R46.1, U6.3 (+)
unnamed: R47.2, R50.1
unnamed: R51.1, U11.4 (~RE)
unnamed: R55.2, U9.2 (DIR)
unnamed: R56.2, U9.22 (~OE)
unnamed: R57.1, U13.5 (DE)
unnamed: R58.2, R60.1
unnamed: R63.2, U9.8 (A6)
unnamed: R64.2, U9.9 (A7)
unnamed: R65.2, U9.10 (A8)

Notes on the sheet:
Slow Overcurrent Detector
MIL Spec DTL-3899 Circular Connectors: https://www.digikey.com/en/products/filter/circular-connectors/circular-connector-assemblies/436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…
Non-Inverting Comparator with Hysteresis Output goes HI when load current goes above 30.5A. Output goes LO when load current goes below 29.5A.
Non-Inverting Comparator with Hysteresis
Fast Overcurrent Delay Timer
f_c = 5.03kHz Rolloff = -24dB/dec Q = 6dB
2N7002 protects VSENSE_MCU line by disconnecting it when VSENSE_MCU > 5V - V_th. VSENSE_MCU clamped to <4V.
Galvanic Isolation
Reverse Polarity Protection
Detects load currents with 150% of nominal maximum load current (>15A) and trips the fault bus within 20s.
Lossy inductive damping leg to reduce filter Q.
FAULT_LATCHED overrides ENABLE to open the high side power switch during any undervoltage or overcurrent event.
Input Power Filter
Shared Fault Bus with Sustained Latch
Undervoltage Lockout Comparator with Hysteresis
Flywheel Diode L_load <= 5mH
Slow Overcurrent Delay Timer
FA-238 Crystal DLmax = 200uW ESRmax = 50R
Cstray = 5pF
FAULT Indicator LED LED illuminates and stays ON for duration of fault bus latch event.
1.5kV Minimum
Communications Power and Data Connector
T = 1us
Supply -
UVLO will engage if supply voltage falls below 10V. UVLO will disengage if supply voltage rises above 12V.
I_z = 5mA max.
Isolated Full-Duplex RS-485 Communication Interface
Debug Connector
COMMS TX Indicator LED
Fast Overcurrent Detector
COMMS POWER Indicator LED
Microcontroller
Protected Voltage Sense Divider
Communications Power Conditioning
PMOS Switch V_ds,max = 100V I_d,max = 37A @ 25°C Ambient
Load +
Flywheel diode for spike suppression during fast changes in input current.
5V to 3V3 Level Shifter
COMMS RX Indicator LED
Non-Inverting Comparator with Hysteresis Output goes HI when load current goes above 15.5A. Output goes LO when load current goes below 14.5A.

Board: 4 copper layers, 166 parts (10 on the bottom side), 97 nets, no tracks yet.

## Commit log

2023-01-16 Initial working sim
    [design_calcs.xlsx, high_side_switch.kicad_pcb, high_side_switch.kicad_sch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]
2023-01-17 Initial release
    [design_calcs.xlsx, high_side_switch-drl_map.dxf, high_side_switch.kicad_pcb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]
2023-02-01 Finalize writeup and clean up a bit
    [proto_high_side_switch.kicad_pcb, proto_high_side_switch.kicad_sch]
